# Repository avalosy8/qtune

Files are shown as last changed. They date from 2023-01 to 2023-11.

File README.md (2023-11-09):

# QTune: Automatic Guitar Tuner
This is a repository for an automatic guitar tuner project. 
This project utilizes the Adafruit Feather RP2040 with CircuitPython.

## Hardware Setup
1. Using the hooks and rubber bands, secure the device on the head of the guitar. Ensure that the tuning pegs are aligned within the tuning attachment that is connected to the servo motor.
2. Using the clip on attachment, clip the piezo sensor on the edge of the guitar's head.
3. Plug the USB to Type-C cable to the power bank and power it on to start the program.
4. Using the push buttons and LCD interface, follow the instructions displayed by the LCD.

## Software Installation
In order to start writing Python scripts for the RP2040, follow these steps:
1. Download the latest version of CircuitPython for the RP2040 here: https://circuitpython.org/board/adafruit_feather_rp2040/
2. Start the bootloader on the board by first plugging in the device, holding down the BOOTSEL button and then pressing the RESET button once. The board will now be mounted as an external filesystem with a name similar to RPI-RP2.
3. Copy the UF2 file onto the mounted board.
4. Connect to the REPL via USB serial port. This can be done using putty or nRF Terminal in VSCode for example.
5. Copy the repo and add the code.py file into the mounted board. The board should flash and run the code.
6. Connect to the USB serial port via the nRF terminal in VSCode or minicom if you're using a Mac.

## Usage
The board controls the servo motors and a LCD based on user input and the processed input frequency from the comparator circuit implementation. The comparator circuit is used to process the analog input from the vibration sensor and convert it to a digital output that can be interpreted in software.

The LCD is connected to two buttons, one button switches between the type of string to be tuned and the second button confirms the string selection. Information is displayed on the LCD as the program progresses.

All of the servo motors are screwed into a 3D printed case, which properly aligns the motors to each tuning peg of the guitar. This case also has two sets of hooks screwed in to allow rubber bands to securely wrap around the device and head of the guitar.

## Overall Procedure
1. Press one button to iterate through all the string options and press the other button to select the current string displayed on the LCD.
2. The selected string will then display on the LCD for a moment before the program initiates the frequency measurements and calculations.
3. As the program runs, it will first measure the frequency and compare it against the target frequency. When it's too low or too high, the LCD will notify the user and the motors will turn either left or right, moving the tuning peg. The user will also be prompted to strum the guitar string again.
4. While the program runs, the user also has the option to restart the program and select a different string to tune. The program restarts by pressing the rightmost button at any point after the program has initiated.
5. If the measured frequency is correct, then the tuning is completed and the program restarts. Otherwise, repeat step 3 until the desired frequency value is measured.

## Demo

Demo (https://www.youtube.com/watch?v=emY8-uXGGco)

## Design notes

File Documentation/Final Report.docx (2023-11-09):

Q-Tune: Final Report

Yenessa Avalos-Maldonado, Timothy Chiles, William Trigg, Giovanni Cornejo, and Dakota Cappel

Github Link: https://github.com/avalosy8/qtune

Abstract

The process of tuning a guitar can be a daunting task for guitarists, especially for beginner guitarists who have yet to develop the skill to tune a guitar by ear. Even experienced guitarists find it challenging to maintain their guitar in tune for extended periods. This project aims to tackle this problem by developing an automatic guitar tuner that can precisely and efficiently tune each string in a guitar. The tuner can analyze the frequency of the guitar string vibrations using a piezo sensor and provide instant adjustments using servo motors attached to each tuning peg of a guitar.

The tuner features a visual display using an LCD that helps guide the user throughout the tuning process by displaying the string selection, its targeted frequency, and overall tuning progress. Each tuning peg is attached to its own servo motor that twists the pegs. To maintain accuracy and reliability, the tuner utilizes a piezoelectric sensor to capture the vibration frequency from the string. Additionally, a rechargeable power bank is used to power the device via a USB type-C cable, which is connected to the Adafruit RP2040 microcontroller. In general, the tuner aims to develop a solution that can ease the process of tuning a guitar. The device is enclosed in a 3D-printed case that can clamp onto the head of the guitar. Ultimately, the project investigates how to enhance the overall guitar playing experience.

Introduction

The main goal of this project is to make the process of tuning a guitar easier, more accurate, and automated. Tuning an instrument is a universal struggle among musicians, and for guitarists this is no exception. Depending on how out of tune a guitar is, it can take as long as 15 to 20 minutes to get all strings back in tune. In addition, most guitarists must use a device that reads the note’s frequency and tells the guitarist whether it is still too high or low. While more experienced guitarists can memorize how each string sounds and tune it accurately, it still requires them to turn each peg an appropriate amount.

Our project intends to serve a need for all guitarists regardless of their skill level, which is to tune a guitar much faster by providing an easy-to-understand user interface. This user interface consists of a LCD screen and two buttons, and the latter allows the user to select which string they want to tune by cycling through the strings. Therefore, all the user must do is to attach the servos to the tuning pegs, select which string they want to tune, and strum the guitar until the LCD outputs a completion message. The screen can either tell the user to keep strumming, or that the tuning process is finished, while using a progression bar. The user can then move onto the next string, if needed. This overall improvement to the speed and reliability of the tuning process is something any guitarist will appreciate, and the stated elements above help achieve this improvement.

For this project, we largely focused on cultural, social and economic factors that could influence the development of our device. This includes the difficulty of upscaling production of our device because of its many separate parts, how the speed of setup would impact use among consumers, and the ability of novel guitarists to use the device to tune their guitar, to name a few. Considering our device involves moving servo parts, we would suggest that users refrain from putting their fingers near the tuning pegs as they turn. Otherwise, this project is largely disconnected from matters of public health, safety, or welfare.

Background

Analog guitar tuners were invented in 1936 and replaced with digital tuners in the 1980s. An issue that these original microphone-based guitar tuners exhibited was that they were much less effective in loud environments due to background noise. This issue was resolved in 1995 when the first clip-on guitar tuner was released that utilized a contact microphone that senses the physical vibrations of the guitar’s wood rather than the sound waves traveling through the air. Since this breakthrough, developments have been made towards automating the entirety of the tuning process. Automatic guitar tuners currently take two forms: the handheld motorized guitar tuners that the user must hold up to each string one by one (see Figure 1) and the built in guitar tuners that come installed in certain guitars (see Figure 2).

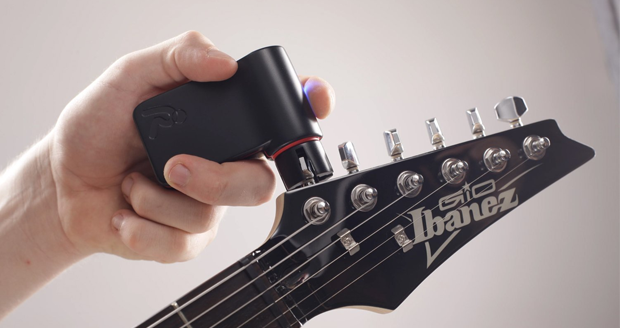
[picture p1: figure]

Figure 1: Handheld Automatic Guitar Tuner

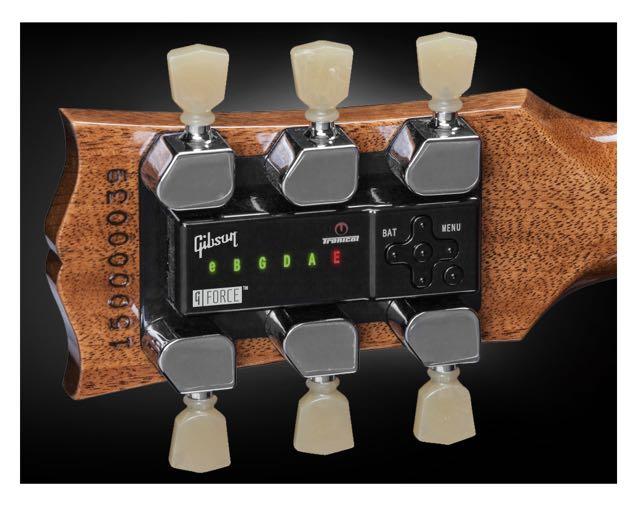
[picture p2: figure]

Figure 2: Built-in Automatic Guitar Tuner

Guitars produce sound via the oscillations of the strings when the strings are plucked. These oscillations get transferred to the body of the guitar via vibrations. The length, thickness, and tension of each guitar string determine the frequency with which the string will vibrate and, in turn, the note that the string will produce. Before playing, the frequency of each full-length string needs to be set to a reference note. Because the length and thickness of an open guitar string are constant, setting the reference note is achieved by adjusting the tension of the string with the tuning pegs at the head of the guitar. The standard reference notes and frequencies are, in order from top to bottom, E (82.41 Hz), A (110.00 Hz), D (146.83 Hz), G (196.00 Hz), B (246.94 Hz), and E (329.63 Hz). Guitar tuners convert the sound of each open string into an equivalent sinusoidal voltage, determine the sinusoid’s frequency, and compare it to these reference values to determine if the string is in tune.

While each guitar string vibrates primarily with its fundamental frequency, it technically oscillates at a superposition of its fundamental frequency and its harmonics, which are integer multiples of the fundamental frequency. To account for these other frequencies, different techniques could be utilized. One such approach would be to filter out the higher harmonic frequencies via analog or digital filtering techniques. While this approach could be used to filter out many of the harmonic frequencies producible by the guitar strings, it would not filter out the multiples of the lower frequency strings that are still smaller than the higher strings. Because the harmonics are integer multiples of the fundamental, a simple digital approach to account for harmonics would be to check for not only the fundamental frequency being present but to also check for twice the frequency, three times the frequency, and onwards.

As mentioned previously, contact microphones have widely been utilized in clip-on guitar tuners. Contact microphones are implemented using piezoelectric transducers. These sensors produce charge on their nodes that is proportional to the mechanical stress applied to their surfaces. These sensors are sensitive enough to pick up the small vibrations produced at the head of a guitar; however, the charge produced by such vibrations is very small. The signal produced by piezo sensors is often driven through an amplifier circuit to increase its amplitude to an appropriate level for subsequent circuitry.

Amplifiers with high input impedance are often used to match the high source impedance of piezo sensors. While voltage-mode amplifiers are often used, charge amplifiers are more recommended for piezo sensors. While the charge produced by the sensor produces a voltage across the piezo sensor’s two plates, this voltage is not necessarily proportional to the charge due to the ability of the capacitance to change between the two nodes. The capacitance can change because the two nodes are often connected to the circuitry via a cable. Changing this length of cable or even adjusting the cable could alter the capacitance of the cable and corrupt the signal from the piezo. Utilizing a charge amplifier nulls this effect as the charge is forced onto one of the plates of the feedback capacitor in the circuit whose value does not change. Additionally, a charge amplifier’s input resistance forms a high-pass filter with the piezo’s capacitance, and the feedback capacitor and resistor form a low-pass filter. The charge amplifier can thus be used to achieve a bandpass response which is useful in many applications.

When it comes to motors, there are many types of motors that could be used to tune a guitar. Servo motors can offer a large amount of torque while limiting the size and the power needed. Using three wires, ground, power, and data, the servo motors can be controlled through pulses from a microcontroller pin. The data channel for the servo motor is constantly receiving pulses from the controller. When wanting to move the motor with a certain power, the width of this pulse changes to a certain value, indicating the motor to move. This type of communication is called Pulse-width modulation. Servos can come in limited rotation or full 360 degree rotation. Both operate in the same manner, however, the limited rotation only offers about 180 degrees of rotation. This can be useful in some cases, but for a guitar tuner, a full 360 rotation is required to ensure that the tuner can always turn each way no matter where it starts.

Timeline

We began the project with some research on how we might develop an automatic guitar tuner. This research led us towards a plan to use a piezoelectric transducer to sense the vibrations of the guitar strings in conjunction with servo motors to turn the motors based on a frequency calculation. To bootstrap the project for the pre-alpha build, we utilized parts we had on hand and began experimenting with calculating frequencies and turning servo motors. We decided that the simplest method would be to convert the sinusoids from a guitar into a square wave and calculate the frequency by timing the period between rising edges. To convert the sinusoids into square waves, we constructed a simple op-amp comparator circuit. Because we had not acquired a piezoelectric sensor yet, we fed sinusoids into the comparator using a waveform generator. We utilized an oscilloscope to verify that the comparator successfully converted the inputted sinusoid into a square wave with the same frequency. During this process, we utilized CircuitPython on our Adafruit RP2040 microcontroller to quickly get a simple micro servo motor to turn clockwise and counterclockwise. Because we planned to use interrupts to time the periods of the square waves from the comparator, we were led to utilize asyncio in CircuitPython to get interrupt-like functionality that could successfully calculate the frequency of our square waves.

When progressing towards our prototype build, we realized that the servo we were using could only turn 90 degrees in both directions which would not suit our needs if our guitar was more than a quarter-turn out of tune. We ordered continuous servo motors that could continuously turn clockwise or counterclockwise and rewrote our code to accommodate these new motors. In addition, we wrote functions that could rotate the servo motors in increments in either direction based on the frequency that another section of our code calculated. We introduced the UI during the prototype phase but did not connect them to the remainder of the tuner. We acquired a piezo sensor during this period and began testing our comparator circuit/firmware with it. We initially played pure tones on our laptop speakers and attempted to pick up the vibrations with our sensor. Testing the piezo with speakers and then a guitar introduced a lot of randomness and inconsistency with our analog signal and thus our frequency we calculated in our firmware. One of the causes of the inconsistency we discovered was that there was an input DC offset that our comparator would introduce to our piezo’s AC signal that would change over time and affect our outputted square waves. We implemented safety guards in code to ignore frequencies that were too far from the frequency of the current string being tuned to account for the noise. In addition, inaccuracies in our calculated frequencies would arise in the code due to how we were directly timing the periods of the square waves.

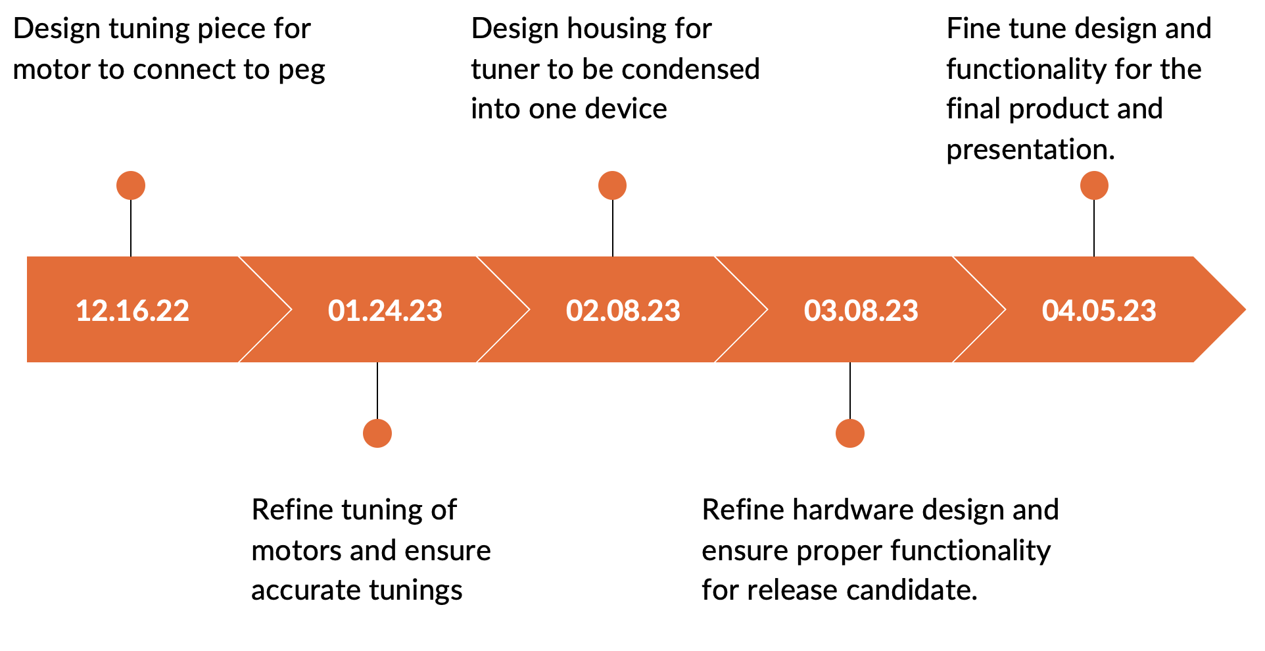
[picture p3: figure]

Figure 4: Prototype Project Timeline

For our alpha build, we primarily upgraded our motor turning and UI systems to better test our ability to tune a guitar. We upgraded our micro servos to much larger servos that could actually turn the tuning pegs of a guitar. In addition, we designed and 3D printed attachments that could attach the motors to the tuning pegs to allow them to turn the pegs. We integrated the UI with the rest of the design and began testing the whole tuning process. We altered sections of the code to get the frequency calculations to be more accurate despite the added complexity of the motors; however, we still had the same inconsistency problems as during the prototype phase.

We addressed the inconsistencies in the frequency calculations during the beta build phase of the project. After much research and experimentation, we designed a charge amplifier circuit to amplify our piezo signal. We discovered that very high frequencies were appearing at the output of our charge amplifier and designed a bandpass filter to filter these frequencies and undesired low frequencies out. To get rid of the changing DC offset that we were experiencing, we added an AC coupling capacitor to block an DC component from entering the comparator. After many bandpass filtering attempts, we realized that the large frequencies we were noticing were the 2nd harmonics of the strings we were strumming. To account for these 2nd harmonics, we added checks in code to check for double the desired frequencies. During this phase, we expanded to 6 motors with tuning attachments.

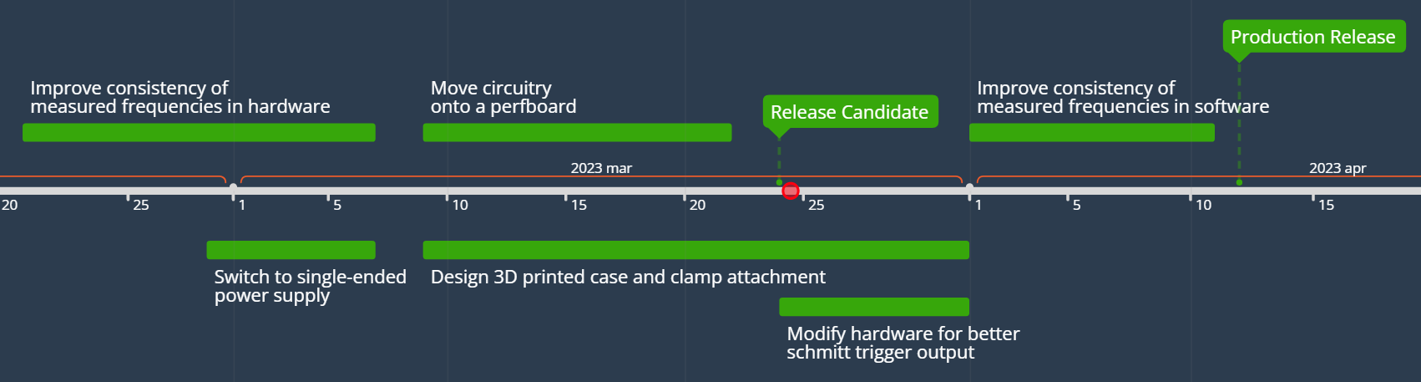
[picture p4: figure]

Figure 5: Project Timeline (Beta Build - Production Release)

Because most of the high frequencies were just 2nd harmonics, we removed the discrete bandpass filter for the release candidate. We also moved all of our circuitry to a single 3.3V supply during this phase. Despite all of the improvements to the signal conditioning circuitry, we still had a lot of inconsistency and inaccuracy in calculating frequencies. We shifted our circuitry to a perfboard and used a higher quality piezo cable to remove some randomness from the circuitry. We also shifted to an actual comparator based square wave generator rather than an op-amp based one. We added hysteresis to the comparator to prevent faulty triggering due to noisy signals. Due to the problems we were having discretely timing square wave periods while turning motors in the background, we shifted away from asyncio and found a synchronous way to calculate frequencies/turn the motors. We utilized the pulsein function, averaging, and other statistics to get a very accurate frequency that we tested against other commercial guitar tuners. We designed a case that could house the motors and all circuitry to mount to the headstock of a guitar and line up the motors, the piezo sensor. This case would attach to the guitar via clamps.

For the production release, we removed the clamps and utilized rubber bands to strap the tuner case to the guitar. We made aesthetic changes to our tuner case as well as some LCD messaging changes to enhance the user experience such as adding a tuning progress notification. We did further testing to enhance the performance of the tuner.

Design

The QTune automatic guitar tuner comprises three peripheral systems: the frequency measurement system, the tuning peg turning system, and the user interface system. The functionality of and communication between these peripheral systems is handled by an Adafruit RP2040 microcontroller whose firmware is written with CircuitPython. All these components physically interface with the guitar via a custom 3D printed case and are powered by a USB power bank.

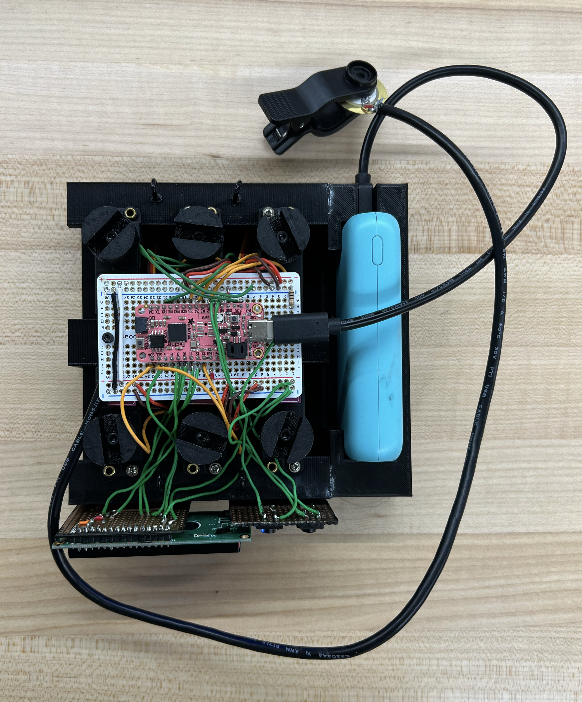
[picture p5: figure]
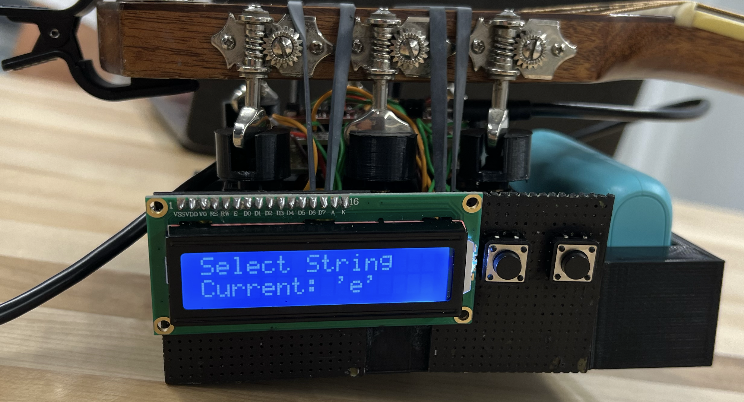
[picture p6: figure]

Figure 3: Top down view of the completed Release Candidate (left). Side view of the device clamped onto the guitar, with the motor tuning attachment properly fitting onto the guitar’s tuning pegs (right).

The frequency measurement system assesses the state of each guitar string as it is tuned by determining the frequency with which the string is vibrating after it is plucked by the user. The tuning peg turning system either turns the string in question clockwise, counterclockwise, or not at all depending on the state of the string reported by the frequency measurement system. The user interface allows users to choose the string that they wish to tune, informs them of when they need to pluck the string, and reports on the progress of the string being tuned with information from the frequency measurement system.

To determine the frequency of the guitar strings, our tuner utilizes a piezoelectric transducer sensor mounted to the headstock of the guitar. The piezoelectric sensor’s positive and negative nodes are wired through a shielded cable into a charge amplifier circuit that amplifies the sensor’s sinusoidal output. The sensor type, input resistor, feedback resistor, and feedback capacitor values were selected to create a passband of around 60 Hz - 360 Hz to filter out frequencies that the guitar could not produce. The sinusoidal output of the charge amplifier is then fed through a schmitt trigger circuit that converts the signal into a clean 0V - 3.3V square wave to be processed by the microcontroller.

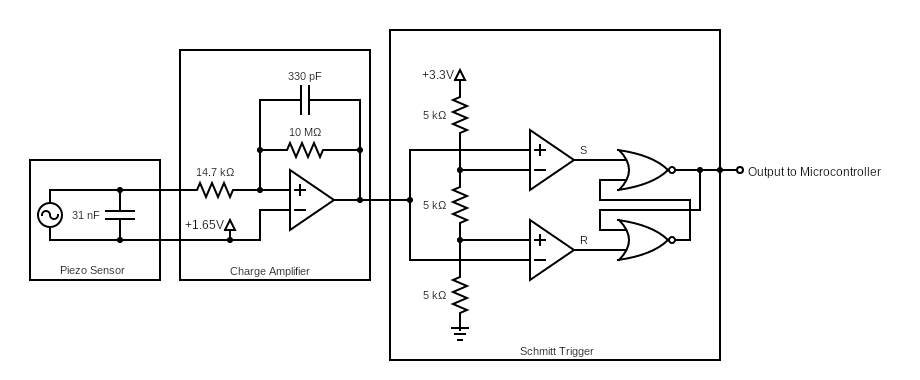
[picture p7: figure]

Figure 6: Piezoelectric Signal Conditioning Circuitry

The frequency is calculated based on the amount of time required for one rising edge and one falling edge - or one period - to be completed, and then taking the reciprocal. This is done via the pulseio module of CircuitPython, which measures a series of active and idle pulses that are read from the rx pin of the microcontroller and stores the times in an array. Accuracy is assured by using the average period time of the array before calculating the frequency. The length of each sample is determined by which note is being played, as higher frequencies require a larger series to maintain accuracy. Precision is assured by repeating this process and storing each measured frequency in another array until ten samples are reached. Only values around the interquartile range are used to remove outliers and then are averaged again to get the final frequency.

The previously calculated frequency will then be compared against the target frequency. The servo attached to the corresponding tuning peg will move either clockwise or counterclockwise depending on if it is higher or lower than the target frequency. If it is within ± 0.5 Hz of the actual value, then it is considered to be in tune and the tuning process is finished.

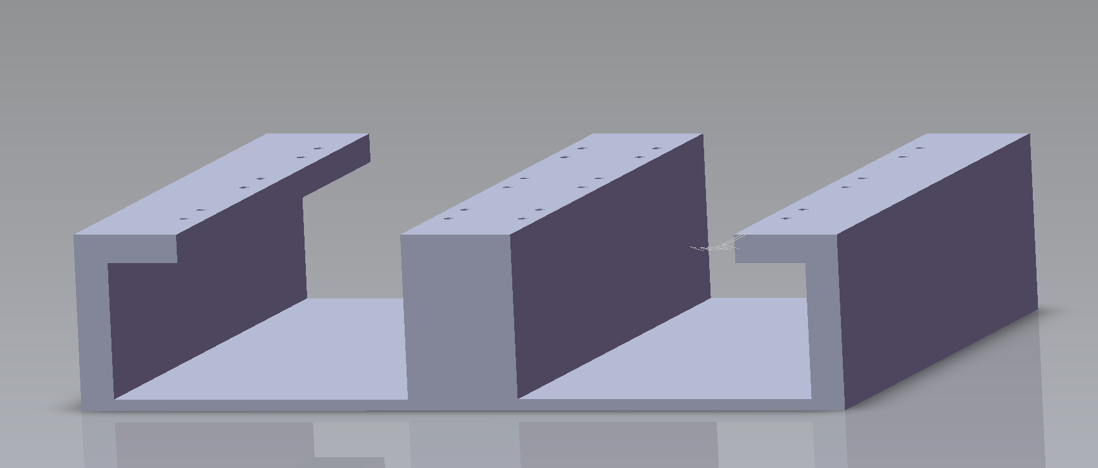
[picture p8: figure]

Figure 7: Finalized case for containing the servo motors, designed in Solidworks. The indicated holes align the motors to the correct tuning pegs.

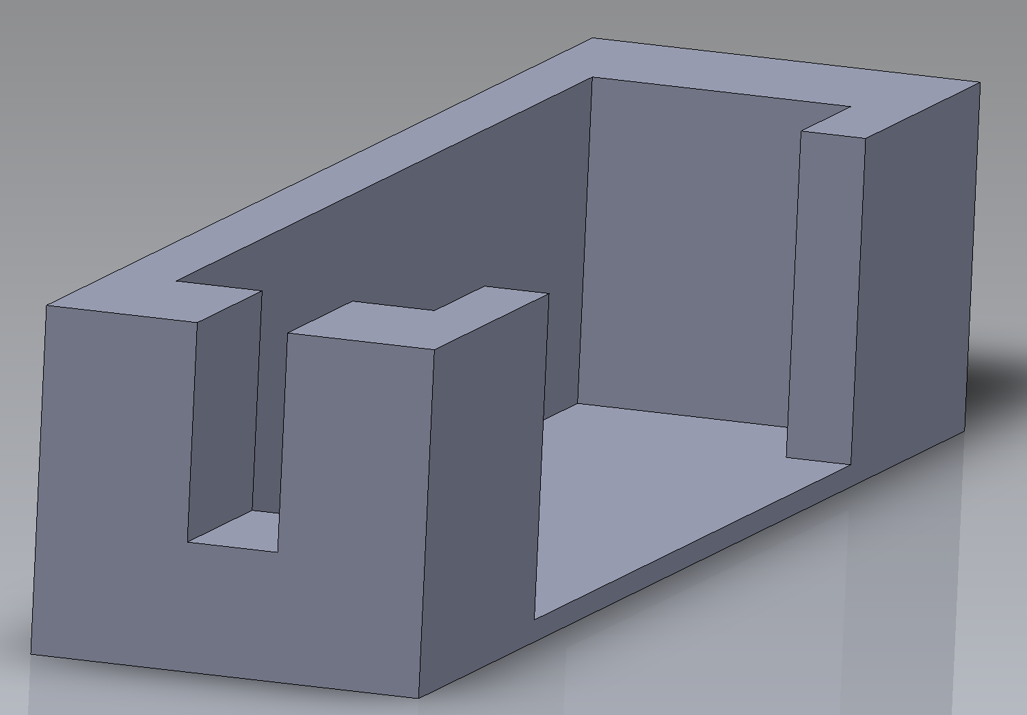
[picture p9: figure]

Figure 8: Finalized case for the power bank, designed in Solidworks.

Impact

To focus on the impact of this project, it’s important to focus on its positive impacts first, starting with its cultural and social impacts. Because this project intends to make the tuning process easier, it allows newer guitarists to continue developing their skills without having to worry about their guitar falling out of tune. This project also removes a learning barrier with people that struggle to get into playing guitar, so more people can actually become musicians. In general, this process should allow more people to become interested in making music, and since music is so intertwined with cultural developments, this project can help develop cultural trends if optimized to its fullest. The device’s compactness, speed of setup, and cost can be further improved with more development time and a generally better piezoelectric sensor. We believe that the device could get this introduction into the industry through smaller record companies or bands, as they could better compete with larger firms and their more advanced technology by speeding up the tuning process. The faster this goes, the easier for them to produce music, and change music and cultural trends sooner.

Considering its cultural and social impacts, one must also recognize its global impact. If this device proves to be a quick and effective tool for tuning guitars, then the technology should be able to spread globally for anyone to use. While English isn’t universally spoken, most countries around the world should be able to understand the technology due to its simplicity and the widespread use of English too. Because our coding is open for anyone to edit, anyone can edit the intended frequencies of each guitar string to tune the guitar to a different key, mode, etc.

In contrast, it’s important to highlight a drawback of the device- its environmental impact. This project requires an external battery source and multiple integrated circuits, and the byproducts of these electronics are often released in wastewater from PCB production facilities. These include chemical agents used to treat the perfboards, heavy metals such as copper and iron, and organic contaminants from the etching process. According to the study done by Geric, et. al, the results demonstrated that the concentration of contaminants of the wastewater was both cytotoxic (decreased viability) and genotoxic (can damage DNA) to human white blood cells. This leaves people more prone to getting sick, among other things. While treating the wastewater is highly effective at controlling this runoff, a lack of regulation can easily lead to contamination of surrounding environments.

Lastly, consider the economic impact of this project. Below is a running total of all the items used for creating the project and their associated costs. The 3D printed casing was done by the Marston Science Library printing lab. Do note that these costs could improve given ownership of a 3D printer and control of production of the servo motors.

Cost Breakdown:

Adafruit IC- $12

3D Printed Main-Body Casing - $15

3D-Printed Battery Case - $7

Piezoelectric Sensors (15 count) - $8

Servo Motors (2 for $16) - $48

Battery Pack- $10

Perfboards ($4.50 each) - $9

The whole cost of the device is approximately $110 dollars, and from a consumer aspect the economic impact becomes clear. Each device produced would cost at least that amount in order to break even, and even more to make a profit. Considering this and other options that consumers have at their disposal for tuning their guitars, they might forgo the automatic aspect of the project and opt for manual tuning with a listening device. Therefore, the economic impact of this project, if realistically marketed and sold in stores, would be limited. The focus would be on the automatic aspect of this device, and its ease of use would see a more niche group of consumers that would want to purchase it, such as beginning musicians.

Finally, in its current state, the device’s main limitation is the sensitivity of the piezo sensor. The comparator circuit and software can read and process all signals correctly, but at certain times, a few strings will have a very short time period where an accurate frequency can be read and processed. This is remedied through multiple strums, but the intended response is to have as few strums as possible. We have attempted to remedy this by shortening the pauses between data collection, with some success.

Results

Alpha Tests

a. Powering/Turning servos
  i. After determining that we had enough available pins on the Adafruit board, we connected all six servo motors and tested different voltages to find the proper voltage level needed to power the motors. After testing, we concluded that 5V was enough to power the motors. We no longer use the default 3.3V on the Adafruit board and instead use the USB pin to obtain 5V.
b. Determining total power required
  i. After testing, we concluded that all components of our guitar tuner could be powered simultaneously via the 5V and 3.3V pins on the Adafruit board. The Adafruit board could successfully power its internal components, the LCD display, the piezo sensor’s circuitry, and at least 1 servo motor at a time via a USB power bank plugged into its USB-C port. We determined that a USB power bank is a suitable power source for our final tuner design as it can make the whole tuner rechargeable and easily able to be turned on and off.
c. Testing 3D printed tuning attachment
  i. Once the tuning attachment design was finalized and printed, we screwed the attachments onto each servo motor and tested them against each tuning peg. We turned the motor in small increments and tested how much strength was needed to turn the tuning peg. After testing, we’ve concluded that the tuning attachment design was a suitable shape for turning the tuning pegs.
d. Testing tuner for each string
  i. As we began testing the accuracy of our tuner, we determined that more circuitry was required to condition the signal from our piezo sensor (amplification, filtering, noise reduction, removal of DC offset). After implementing this new functionality, we encountered an issue where the second harmonic of each string was appearing more so than the fundamental frequency we were looking for. We added to our code to account for this issue. When testing our tuner after these progressions, we achieved our first successful tuning of the low E string.

Beta Tests

a. Guitar string accuracy
  i. In order to ensure that the software was reading the frequencies correctly for each string, we performed a variety of tests for each string. First, we used the DAD and fed in the comparator output to the oscilloscope and had WaveForms calculate the frequency to make sure the comparator was accurate. We compared these results to a clip-on tuner. We then ran the program on the adafruit and had it calculate the frequency and compared it to both the DAD and the clip-on tuner to ensure accuracy. We then put each string out of tune and made sure that software continued to record accurate frequencies. All of these tests were successful, with the software recording nearly perfect readings each time.
b. Motor Tests
  i. We then used the frequency data to feed into the motors to turn the proper direction. We went through each string and put them out of tune and ran through each string and ensured that the motors could properly tune the string within a certain threshold. We first started with a large frequency threshold and slowly made the threshold smaller to make sure the motors could tune very accurately. These tests were very successful with the tuner being able to tune within +/-0.5 Hz.
c. Environmental Tests
  i. We then tested the guitar in different positions to make sure that this did not have an effect on the readings of the guitar and motors tuning. Upon moving the guitar to different positions, such as being held normally instead of flat on the table, the tuner continued to work as expected.
d. Durability Tests
  i. To test durability, we attached the tuner to the end of the guitar and moved it as a normal guitarist might and made sure the tuner did not move much. The tuner would stay on with our current clamp design, however with too much movement, the tuner may fall off. This is expected though, as the design is supposed to be removable and therefore too much movement could potentially make it fall off. With normal, non rigorous movements, the tuner is very stable.

The completed hardware elements of the project include a 3D printed case enclosing all components. Measurements for component lengths and the guitar were taken using a caliper for construction of the case in SolidWorks. This contains the six motors that are each attached to a tuning peg and a small hub that holds a rechargeable power bank to power the device and the LCD and push button user interface. The interface is attached to the outside of the case and painted to match. The circuitry itself has been condensed onto a perfboard to fit neatly between the motors. Consisting of the charge amplifier and schmitt trigger circuits, the output is sent to a secondary perfboard that holds the Adafruit RP2040 microcontroller. All wired connections are also hidden within the case. The enclosure is attached to the guitar with elastic bands that attach to hooks on opposite sides of the device. The tuning pegs of the guitar then fit precisely into the motors of the device allowing the motors to efficiently and accurately tune the guitar.

As for software, the frequency measurements have been cleaned up to produce very accurate results, with frequency readings being almost perfect (within +/- 0.1Hz) in the best case. This allows the device to tune the guitar to within +/- 0.5Hz of the desired frequency. The LCD display continuously shows the current progress of the tuning, notifying users when the tuning is done. The software has also been modified to turn the motors for longer the more out of tune the string is, and shorter the closer it gets, producing much quicker and more accurate results. The users are now also able to exit a tuning and return to the initialization screen if they select the wrong string.

Conclusion

In conclusion, the automatic guitar tuner project aims to develop an innovative solution that can reliably automate the process of tuning a guitar. With features such as an LCD interface with buttons and accurate frequency measurements, the tuner will provide reliable and consistent tuning for both beginners and experienced guitarists. To ensure the device tunes as precisely and accurately as possible, multiple tests and adjustments were made to the design of the tuner throughout the whole process while following proper engineering practices.

Ultimately, the project seeks to enhance the quality and enjoyment of the guitar playing experience, which is done using the device’s intuitive and responsive interface. This device will enhance the guitar playing experience by minimizing the frustrations and time it takes to tune a guitar. Especially for beginner guitarists who have yet developed good intonation, this device will help aspiring guitarists jumpstart their musical journey without having to worry about knowing how to tune.

References

1. Colin, “Guitar tuners 101: The Ultimate Buyer's Guide,” E-Home Recording Studio, 02-Mar-2023. [Online]. Available: https://ehomerecordingstudio.com/best-guitar-tuners/. [Accessed: 24-Mar-2023].
2. E. Moffatt, “Nashville-based Gibson says self-tuning guitars are here to stay,” 90.3 WPLN News, 29-Jun-2015. [Online]. Available: https://wpln.org/post/nashville-based-gibson-says-self-tuning-guitars-are-here-to-stay/. [Accessed: 24-Mar-2023].
3. Evstark and Evstark, “Modeling and experimental tools with prof. magnes,” Modeling and Experimental Tools with Prof Magnes, 12-May-2019. [Online]. Available: https://pages.vassar.edu/magnes/2019/05/12/studying-and-modeling-guitar-harmonics-using-fourier-analysis/. [Accessed: 24-Mar-2023].
4. J. Karki, “Signal conditioning piezoelectric sensors - Texas Instruments,” TI, Sep-2000. [Online]. Available: https://www.ti.com/lit/an/sloa033a/sloa033a.pdf. [Accessed: 25-Mar-2023].
5. M. Gerić, G. Gajski, V. Oreščanin, A.-M. Domijan, R. Kollar, and V. Garaj-Vrhovac, “Environmental risk assessment of wastewaters from printed circuit board production: A multibiomarker approach using human cells Author links open overlay panel,” ScienceDirect, Feb-2017. [Online]. Available: https://doi.org/10.1016/j.chemosphere.2016.10.101. [Accessed: 24-Mar-2023].
6. “Roadie Tuner Automatic guitar tuner,” Agazoo, 10-Jun-2015. [Online]. Available: https://agazoo.com/offers/unique-gadgets/roadie-tuner-automatic-guitar-tuner/. [Accessed: 24-Mar-2023].
7. “Piezo tuners - the clip on Tuner,” SWAMP Industries, 26-Oct-2022. [Online]. Available: https://www.swamp.net.au/articles/piezo-tuners.html. [Accessed: 24-Mar-2023].

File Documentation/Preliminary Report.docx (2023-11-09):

Q-Tune: Preliminary Report

Yenessa Avalos-Maldonado, Timothy Chiles, William Trigg, Giovanni Cornejo, and Dakota Cappel

Github Link: https://github.com/avalosy8/qtune

Abstract

The process of tuning a guitar can be a daunting task for guitarists, especially for beginner guitarists who have yet to develop the skill to tune a guitar by ear. Even experienced guitarists find it challenging to maintain their guitar in tune for extended periods. This project aims to tackle this problem by developing an automatic guitar tuner that can precisely and efficiently tune each string in a guitar. The tuner can analyze the frequency of the guitar string strums using a piezo sensor and provide instant adjustments using servo motors.

The tuner features a visual display using an LCD that helps guide the user throughout the tuning process by displaying the string selection, its targeted frequency, and overall tuning progress. Each tuning peg is attached to its own servo motor that twists the pegs. To maintain accuracy and reliability, the tuner utilizes a piezoelectric sensor to capture the vibration frequency from the string. Additionally, a rechargeable power bank is used to power the device via a USB type-C cable, which is connected to the Adafruit RP2040 microcontroller. In general, the tuner aims to develop a solution that can ease the process of tuning a guitar. The overall device is enclosed in a 3D-printed case that can clamp onto the head of the guitar. Ultimately, the project investigates enhancing the overall guitar playing experience.

Introduction

The main goal of this project is to make the process of tuning a guitar easier, more accurate, and automated. Tuning an instrument is a universal struggle among musicians, and for guitars this is no exception. Depending on how out of tune a guitar is, it can take as long as 15 to 20 minutes to get all strings back in tune. In addition, most guitarists must use a device that reads the note’s frequency and tells the guitarist whether it is still too high or low. While more experienced guitarists can memorize how each string sounds and tune it accurately, it still requires them turning each peg an appropriate amount.

Our project intends to serve a need for all guitarists regardless of their skill level, which is to tune a guitar much faster by providing an easy-to-understand user interface. This user interface consists of a LCD screen and two buttons, and the latter allows the user to select which string they want to tune by cycling through the strings. Therefore, all the user must do is to attach the servos to the tuning pegs by turning them, select which string they want to tune, and strum the guitar until the LCD outputs a completion message. The screen can either tell the user to keep strumming, or that the tuning process is finished. The user can then move onto the next string, or they are done tuning. This overall improvement to the speed and reliability of the tuning process is something any guitarist will appreciate, and the stated elements above help achieve this improvement.

Background

Analog guitar tuners were invented in 1936 and replaced with digital tuners in the 1980s. An issue that these original microphone-based guitar tuners exhibited was that they were much less effective in loud environments due to background noise. This issue was resolved in 1995 when the first clip-on guitar tuner was released that utilized a contact microphone that senses the physical vibrations of the guitar’s wood rather than the sound waves traveling through the air. Since this breakthrough, developments have been made towards automating the entirety of the tuning process. Automatic guitar tuners currently take two forms: the handheld motorized guitar tuners that the user must hold up to each string one by one (see Figure 1) and the built in guitar tuners that come installed in certain guitars (see Figure 2).


Figure 1: Handheld Automatic Guitar Tuner


Figure 2: Built-in Automatic Guitar Tuner

Guitars produce sound via the oscillations of the strings when the strings are plucked. These oscillations get transferred to the body of the guitar via vibrations. The length, thickness, and tension of each guitar string determine the frequency with which the string will vibrate and, in turn, the note that the string will produce. Before playing, the frequency of each full-length string needs to be set to a reference note. Because the length and thickness of an open guitar string are constant, setting the reference note is achieved by adjusting the tension of the string with the tuning pegs at the head of the guitar. The standard reference notes and frequencies are, in order from top to bottom, E (82.41 Hz), A (110.00 Hz), D (146.83 Hz), G (196.00 Hz), B (246.94 Hz), and E (329.63 Hz). Guitar tuners convert the sound of each open string into an equivalent sinusoidal voltage, determine the sinusoid’s frequency, and compare it to these reference values to determine if the string is in tune.

While each guitar string vibrates primarily with its fundamental frequency, it technically oscillates at a superposition of its fundamental frequency and its harmonics, which are integer multiples of the fundamental frequency. To account for these other frequencies, different techniques could be utilized. One such approach would be to filter out the higher harmonic frequencies via analog or digital filtering techniques. While this approach could be used to filter out many of the harmonic frequencies producible by the guitar strings, it would not filter out the multiples of the lower frequency strings that are still smaller than the higher strings. Because the harmonics are integer multiples of the fundamental, a simple digital approach to account for harmonics would be to check for not only the fundamental frequency being present but to also check for twice the frequency, three times the frequency, and onwards.

As mentioned previously, contact microphones have widely been utilized in clip-on guitar tuners. Contact microphones are implemented using piezoelectric transducers. These sensors produce charge on their nodes that is proportional to the mechanical stress applied to their surfaces. These sensors are sensitive enough to pick up the small vibrations produced at the headstock of a guitar; however, the charge produced by such vibrations is very small. The signal produced by piezo sensors is often driven through an amplifier circuit to increase its amplitude to an appropriate level for subsequent circuitry.

Amplifiers with high input impedance are often used to match the high source impedance of piezo sensors. While voltage-mode amplifiers are often used, charge amplifiers are more recommended for piezo sensors. While the charge produced by the sensor produces a voltage across the piezo sensor’s two plates, this voltage is not necessarily proportional to the charge due to the ability of the capacitance to change between the two nodes. The capacitance can change because the two nodes are often connected to the circuitry via a cable. Changing this length of cable or even adjusting the cable could alter the capacitance of the cable and corrupt the signal from the piezo. Utilizing a charge amplifier nulls this effect as the charge is forced onto one of the plates of the feedback capacitor in the circuit whose value does not change. Additionally, a charge amplifier’s input resistance forms a high-pass filter with the piezo’s capacitance, and the feedback capacitor and resistor form a low-pass filter. The charge amplifier can thus be used to achieve a bandpass response which is useful in many applications.

When it comes to motors, there are many types of motors that could be used to tune a guitar. Servo motors can offer a large amount of torque while limiting the size and the power needed. Using three wires, ground, power, and data, the servo motors can be controlled through pulses from a microcontroller pin. The data channel for the servo motor is constantly receiving pulses from the controller. When wanting to move the motor with a certain power, the width of this pulse changes to a certain value, indicating the motor to move. This type of communication is called Pulse-width modulation. Servos can come in limited rotation or full 360 degree rotation. Both operate in the same manner, however, the limited rotation only offers about 180 degrees of rotation. This can be useful in some cases, but for a guitar tuner, a full 360 rotation is required to ensure that the tuner can always turn each way no matter where it starts.

Design

The QTune automatic guitar tuner comprises three peripheral systems: the frequency measurement system, the tuning peg turning system, and the user interface system. The functionality of and communication between these peripheral systems is handled by an Adafruit RP2040 microcontroller whose firmware is written with CircuitPython. All these components physically interface with the guitar via a custom 3D printed case and are powered by a USB power bank.

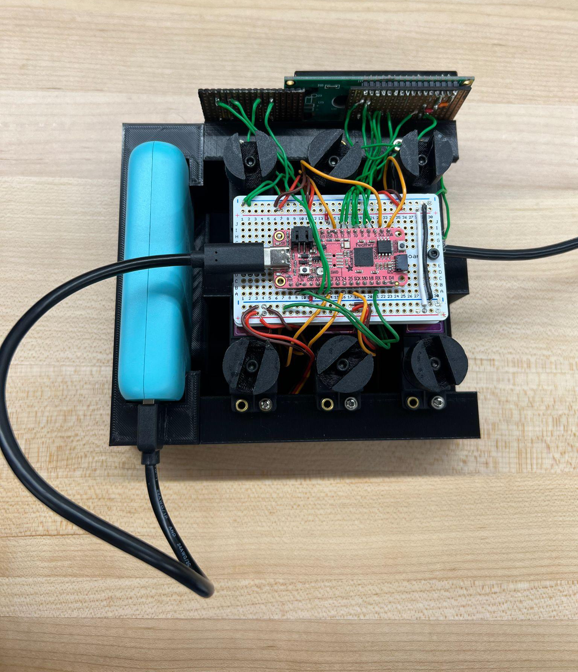
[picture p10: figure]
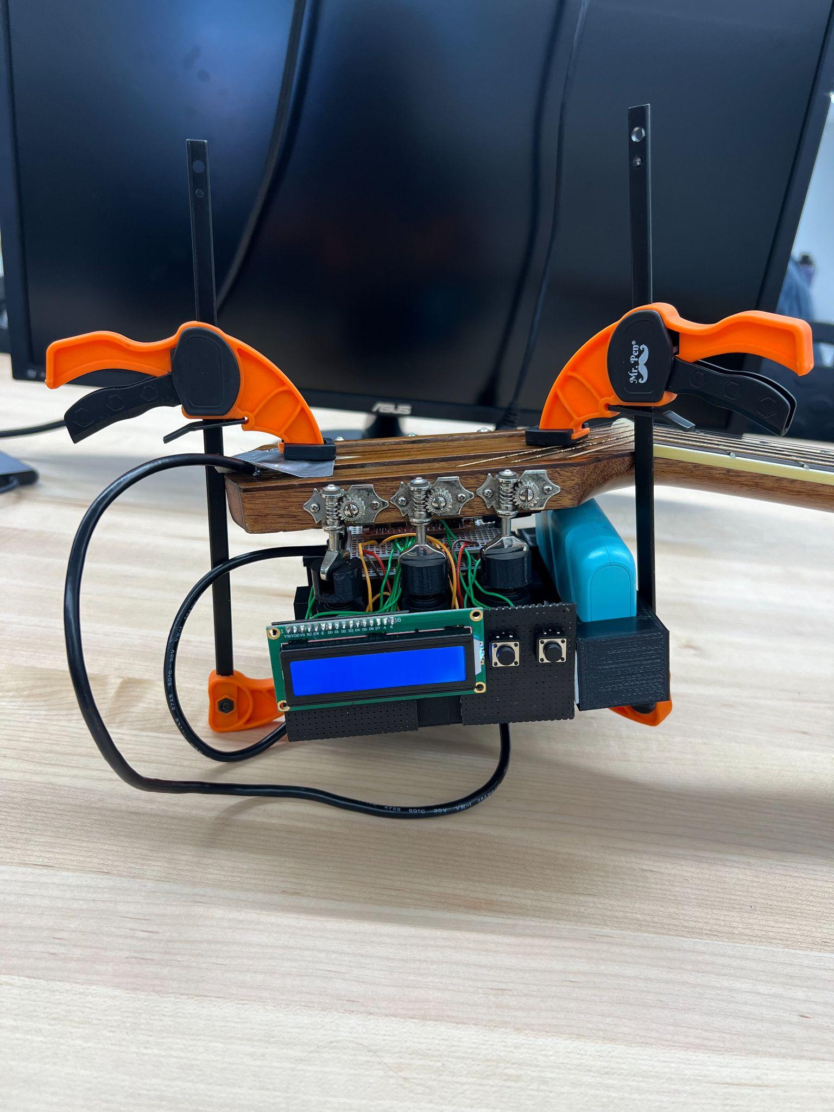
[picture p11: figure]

Figure 3: Top down view of the completed Release Candidate (left). Side view of the device clamped onto the guitar, with the motor tuning attachment properly fitting onto the guitar’s tuning pegs (right).

The frequency measurement system assesses the state of each guitar string as it is tuned by determining the frequency with which the string is vibrating after it is plucked by the user. The tuning peg turning system either turns the string in question clockwise, counterclockwise, or not at all depending on the state of the string reported by the frequency measurement system. The user interface allows users to choose the string that they wish to tune, informs them of when they need to pluck the string, and reports on the progress of the string being tuned with information from the frequency measurement system.

To determine the frequency of the guitar strings, our tuner utilizes a piezoelectric transducer sensor mounted to the headstock of the guitar. The piezoelectric sensor’s positive and negative nodes are wired through a shielded cable into a charge amplifier circuit that amplifies the sensor’s sinusoidal output. The sensor type, input resistor, feedback resistor, and feedback capacitor values were selected to create a passband of around 60 Hz - 360 Hz to filter out frequencies that the guitar could not produce. The sinusoidal output of the charge amplifier is then fed through a schmitt trigger circuit that converts the signal into a clean 0V - 3.3V square wave to be processed by the microcontroller.


Figure 4: Piezoelectric Signal Conditioning Circuitry

The frequency is calculated based on the amount of time required for one rising edge and one falling edge - or one period - to be completed, and then taking the reciprocal. This is done via the pulseio module of CircuitPython, which measures a series of active and idle pulses that are read from the rx pin of the microcontroller and stores the times in an array. Accuracy is assured by using the average period time of the array before calculating the frequency. The length of each sample is determined by which note is being played, as higher frequencies require a larger series to maintain accuracy. Precision is assured by repeating this process and storing each measured frequency in another array until ten samples are reached. Only values around the interquartile range are used to remove outliers and then are averaged again to get the final frequency.

The previously calculated frequency will then be compared against the target frequency (the note being tuned). The servo attached to the corresponding tuning peg will move clockwise or counterclockwise depending on if it is higher or lower than the target frequency. If it is within ± 1 Hz of the actual value, then it is considered to be in tune and the tuning process is finished.


Figure 5: Case for containing the servo motors, designed in Solidworks. The indicated holes align the motors to the correct tuning pegs.

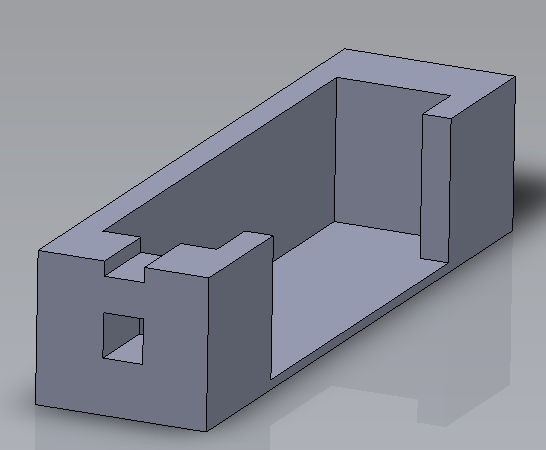
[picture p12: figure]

Figure 6: Case for the power bank, designed in Solidworks.

Impact

This project’s impact will be mostly cultural. Because this project intends to make the tuning process easier, it allows newer guitarists to continue developing their skills without having to worry about their guitar falling out of tune. This should allow more people to become interested in making music, and since music is so intertwined with cultural developments, this project can help develop cultural trends if optimized to its fullest.

In contrast, it’s important to highlight a drawback of the device- its environmental impact. This project requires an external battery source and multiple integrated circuits, and the byproducts of these electronics are often released in wastewater from PCB production facilities. These include chemical agents used to treat the perfboards, heavy metals such as copper and iron, and organic contaminants from the etching process. According to the study done by Geric, et. al, the results demonstrated that the concentration of contaminants of the wastewater was both cytotoxic (decreased viability) and genotoxic (can damage DNA) to human white blood cells. While treating the wastewater is highly effective at controlling this runoff, a lack of regulation can easily lead to contamination of surrounding environments.

Lastly, in its current state, the device’s main limitation is the sensitivity of the piezo sensor. The comparator circuit and software can read and process all signals correctly, but at certain times, a few strings will have a very short time period where an accurate frequency can be read and processed. This is remedied through multiple strums, but the intended response is to have as few strums as possible.

Results

Alpha Tests

a. Powering/Turning servos
  i. After determining that we had enough available pins on the Adafruit board, we connected all six servo motors and tested different voltages to find the proper voltage level needed to power the motors. After testing, we concluded that 5V was enough to power the motors. We no longer use the default 3.3V on the Adafruit board and instead use the USB pin to obtain 5V.
b. Determining total power required
  i. After testing, we concluded that all components of our guitar tuner could be powered simultaneously via the 5V and 3.3V pins on the Adafruit board. The Adafruit board could successfully power its internal components, the LCD display, the piezo sensor’s circuitry, and at least 1 servo motor at a time via a USB power bank plugged into its USB-C port. We determined that a USB power bank is a suitable power source for our final tuner design as it can make the whole tuner rechargeable and easily able to be turned on and off.
c. Testing 3D printed tuning attachment
  i. Once the tuning attachment design was finalized and printed, we screwed the attachments onto each servo motor and tested them against each tuning peg. We turned the motor in small increments and tested how much strength was needed to turn the tuning peg. After testing, we’ve concluded that the tuning attachment design was a suitable shape for turning the tuning pegs.
d. Testing tuner for each string
  i. As we began testing the accuracy of our tuner, we determined that more circuitry was required to condition the signal from our piezo sensor (amplification, filtering, noise reduction, removal of DC offset). After implementing this new functionality, we encountered an issue where the second harmonic of each string was appearing more so than the fundamental frequency we were looking for. We added to our code to account for this issue. When testing our tuner after these progressions, we achieved our first successful tuning of the low E string.

Beta Tests

a. Guitar string accuracy
  i. In order to ensure that the software was reading the frequencies correctly for each string, we performed a variety of tests for each string. First, we used the DAD and fed in the comparator output to the oscilloscope and had WaveForms calculate the frequency to make sure the comparator was accurate. We compared these results to a clip-on tuner. We then ran the program on the adafruit and had it calculate the frequency and compared it to both the DAD and the clip-on tuner to ensure accuracy. We then put each string out of tune and made sure that software continued to record accurate frequencies. All of these tests were successful, with the software recording nearly perfect readings each time.
b. Motor Tests
  i. We then used the frequency data to feed into the motors to turn the proper direction. We went through each string and put them out of tune and ran through each string and ensured that the motors could properly tune the string within a certain threshold. We first started with a large frequency threshold and slowly made the threshold smaller to make sure the motors could tune very accurately. These tests were very successful with the tuner being able to tune within +/-1Hz.
c. Environmental Tests
  i. We then tested the guitar in different positions to make sure that this did not have an effect on the readings of the guitar and motors tuning. Upon moving the guitar to different positions, such as being held normally instead of flat on the table, the tuner continued to work as expected.
d. Durability Tests
  i. To test durability, we attached the tuner to the end of the guitar and moved it as a normal guitarist might and made sure that the tuner did not move too much. The tuner would stay on with our current clamp design, however with too much movement, the tuner may fall off. This is expected though, as the design is supposed to be removable and therefore too much movement could potentially make it fall off. However, with normal, non rigorous movements, the tuner is very stable.

Status

The completed hardware elements of the project include a 3D printed case enclosing all components. Measurements for component lengths and the guitar were taken using a caliper for construction of the case in SolidWorks. This contains the six motors that are each attached to a tuning peg and a small hub that holds a rechargeable power bank to power the device and the LCD and push button user interface. The interface is attached to the outside of the case and painted to match. The circuitry itself has been condensed onto a perfboard to fit neatly between the motors. Consisting of the charge amplifier and schmitt trigger circuits, the output is sent to a secondary perfboard that holds the Adafruit RP2040 microcontroller. All wired connections are also hidden within the case. As for software, the accuracy of the frequency measurements has been improved enough to allow for correct tuning of the low E, D, and high E strings consistently.

Currently in progress is the design of a clamp to secure the device to the guitar. Also, the A, G, and B strings do not have a long enough signal received from each strum to get correct frequency measurements and instead need multiple strums to reach ten samples. Therefore, the charge amplifier and piezo sensor will be slightly modified to allow for more output to appear from the schmitt trigger. Once this is finished, the last planned element will be to further improve the measurements on the A, G, and B strings based on these changes. With a longer signal, more samples can be taken from a single strum of the guitar and will allow for less strums required to tune and a higher quality frequency being measured for all notes.


Figure 7: Project Timeline (Beta Build - Production Release)

Conclusion

In conclusion, the automatic guitar tuner project aims to develop an innovative solution that can make the process of tuning a guitar easier. With features such as an LCD interface with buttons and accurate frequency measurements, the tuner will provide reliable and consistent tuning for both beginners and experienced guitarists. Ultimately, the project seeks to enhance the quality and enjoyment of the guitar playing experience.

As for the future of this project, based on its current state at this time, additional testing can be made to optimize the frequency measurements. Our planned approach is to test different sensors to obtain a larger set of readings. Since all features have been implemented, the sensor can be replaced without it entirely altering the current state of this project. Overall, this project can currently tune a guitar reliably.

References

1. Colin, “Guitar tuners 101: The Ultimate Buyer's Guide,” E-Home Recording Studio, 02-Mar-2023. [Online]. Available: https://ehomerecordingstudio.com/best-guitar-tuners/. [Accessed: 24-Mar-2023].
2. E. Moffatt, “Nashville-based Gibson says self-tuning guitars are here to stay,” 90.3 WPLN News, 29-Jun-2015. [Online]. Available: https://wpln.org/post/nashville-based-gibson-says-self-tuning-guitars-are-here-to-stay/. [Accessed: 24-Mar-2023].
3. Evstark and Evstark, “Modeling and experimental tools with prof. magnes,” Modeling and Experimental Tools with Prof Magnes, 12-May-2019. [Online]. Available: https://pages.vassar.edu/magnes/2019/05/12/studying-and-modeling-guitar-harmonics-using-fourier-analysis/. [Accessed: 24-Mar-2023].
4. J. Karki, “Signal conditioning piezoelectric sensors - Texas Instruments,” TI, Sep-2000. [Online]. Available: https://www.ti.com/lit/an/sloa033a/sloa033a.pdf. [Accessed: 25-Mar-2023].
5. M. Gerić, G. Gajski, V. Oreščanin, A.-M. Domijan, R. Kollar, and V. Garaj-Vrhovac, “Environmental risk assessment of wastewaters from printed circuit board production: A multibiomarker approach using human cells Author links open overlay panel,” ScienceDirect, Feb-2017. [Online]. Available: https://doi.org/10.1016/j.chemosphere.2016.10.101. [Accessed: 24-Mar-2023].
6. “Roadie Tuner Automatic guitar tuner,” Agazoo, 10-Jun-2015. [Online]. Available: https://agazoo.com/offers/unique-gadgets/roadie-tuner-automatic-guitar-tuner/. [Accessed: 24-Mar-2023].
7. “Piezo tuners - the clip on Tuner,” SWAMP Industries, 26-Oct-2022. [Online]. Available: https://www.swamp.net.au/articles/piezo-tuners.html. [Accessed: 24-Mar-2023].

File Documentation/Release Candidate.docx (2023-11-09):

Q-Tune: Release Candidate

Yenessa Avalos-Maldonado, Timothy Chiles, William Trigg, Giovanni Cornejo, and Dakota Cappel

Github Link: https://github.com/avalosy8/qtune


Figure 1: Top down view of the completed Release Candidate (left). Side view of the device clamped onto the guitar, with the motor tuning attachment properly fitting onto the guitar’s tuning pegs (right).

External Interface

Our automatic guitar tuner’s external interface consists of a piezo vibration sensor, which connects as an input to the op-amp comparator circuit, and a servo motor that is driven by an output pin from the Adafruit RP 2040. The output of the comparator circuit is the input to the RX pin of the RP 2040, which is polled to start the frequency calculations. The external interface connects to the persistent state by the use of state variables and constants in memory, which are used to store the data obtained from the vibration sensor and comparator circuit. Additionally, all the hardware components have been condensed to fit within a 3D case as shown in Figure 1. The circuitry components have been moved and soldered onto two perfboards, one containing the Adafruit board and another containing the charge amplifier, filters, and comparator circuit. The entire device is attached to the guitar’s head using two clamps.

Persistent State

The guitar tuner stores its data via state variables and constants in memory. The constants are stored in onboard flash memory and are necessary for our internal tuning systems to run properly. The state variables are stored in RAM on the Adafruit board and are updated in response to input from the frequency-detecting components of our external interface. The persistent state connects to the external interface of our build through pins on the RP2040 microcontroller. The RX pin from the external interface is polled to start the frequency calculations. The persistent state stores this information to determine if the motors from our external interface need to turn the tuning pegs on the guitar. The persistent state connects to the interface system by also utilizing stored variables in order to process the necessary data to allow each component of our internal system to properly process data.

Internal Systems

Our three main internal systems are our frequency-detection system to determine the tuning of the guitar, our motor-turning system to alter the tuning of the guitar, and our UI system to allow users to interface with our guitar tuner. More advanced versions of the data processing involved in our three systems have been implemented. At present, the frequency-detection system can calculate the frequency of a guitar string via the external piezo sensor circuitry to some degree of accuracy. The motor-turning system can turn the motors in response to the frequency calculated with some degree of precision. The UI system allows users to select the string they want to tune and reports the tuner’s progress as a percentage. The internal system connects to the persistent state by the use of state variables and constants in memory to process the gathered data from each component.

Communication

The user will be interfacing with the LCD screen and two push buttons as a means of interacting with the tuner. The push buttons will be accessible to the user near the LCD screen, on the left and right side. These buttons accurately detect a selection made by the user and displays the correct string that was selected and its targeted frequency. Thus, the user will be able to intuitively select the desired string to tune. After making a selection,the user will just have to view the LCD screen to be notified about whether the guitar string needs to be strummed again based on tuning percentage. When the measured frequency isn’t close to the target frequency within an acceptable range then the motors move the tuning peg as expected and the user is prompted to strum the guitar string again.

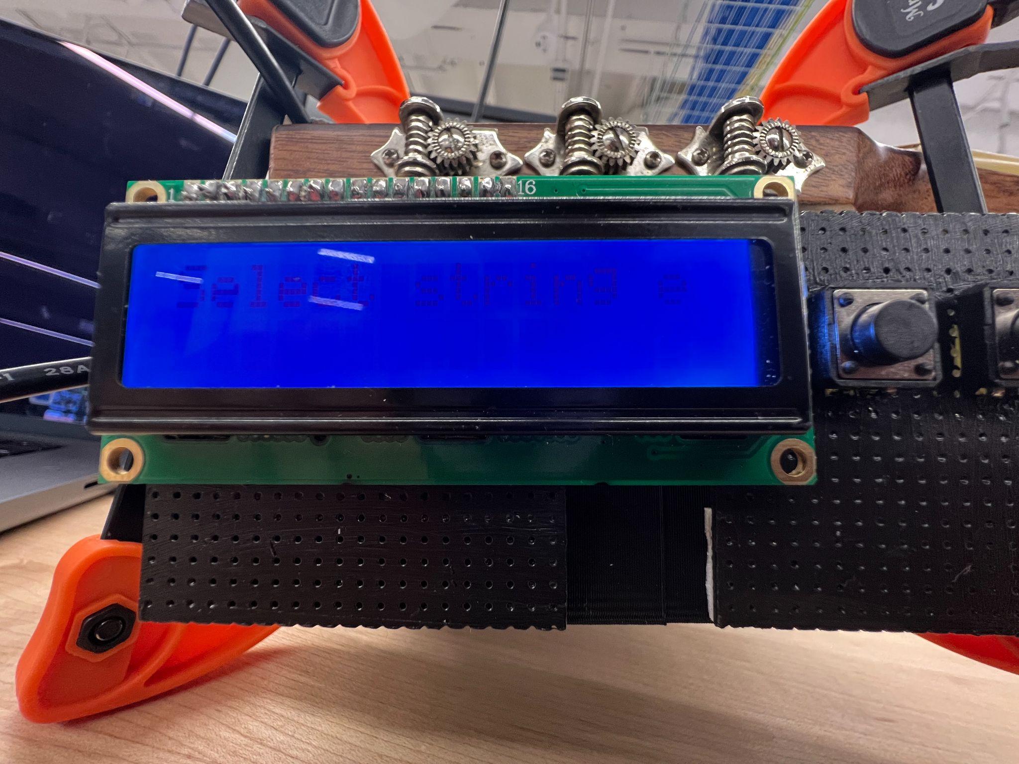
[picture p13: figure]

Figure 2: User is first prompted to select a string.

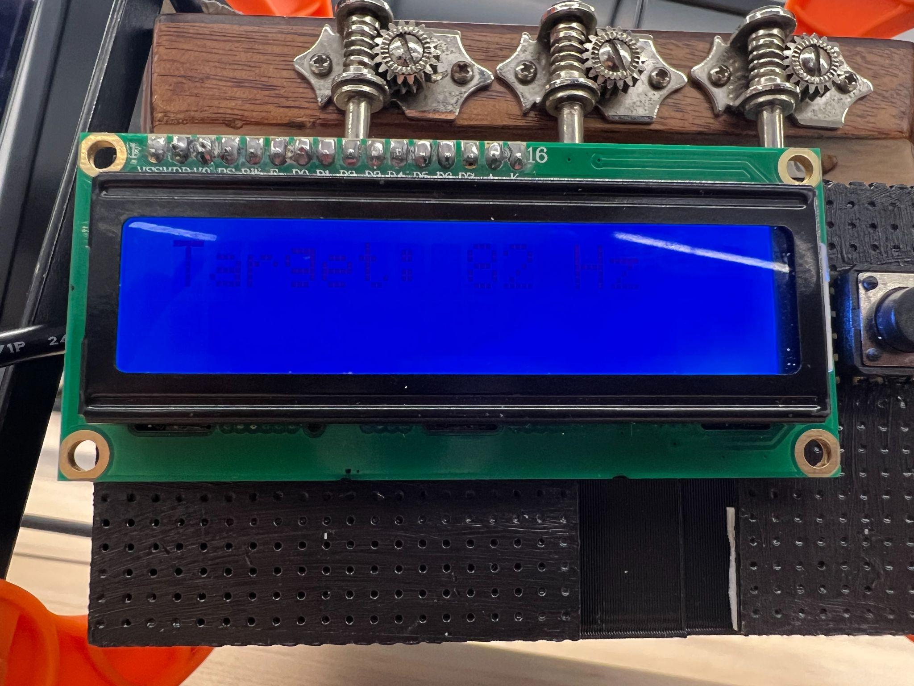
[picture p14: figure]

Figure 3: After the string is selected, its target frequency is displayed.

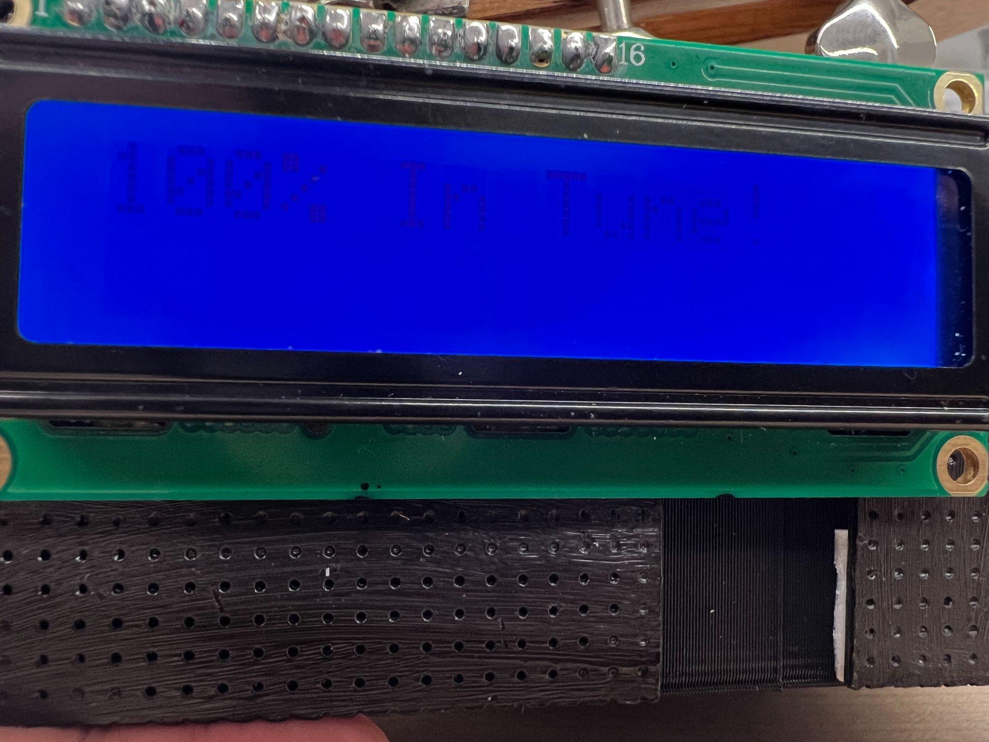
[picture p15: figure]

Figure 4: Percentage of how tuned the selected string is. This is displayed after the frequency is measured.

Integrity & Resilience

When running the program normally, the device is able to run through menu options, display the desired frequency, display the measured frequency and tuning progress percentage, and turn the motor without any crashing or system failures. There are multiple filters in-place, both in hardware and software, to ensure that the system does not pick up unwanted frequencies and produce undesired results such as improper tuning. When the second harmonic of the strings appears more strongly at the input than its fundamental frequency, our code has the infrastructure in place to account for the doubled frequencies. All random instances of crashes have been debugged and dealt with as well, creating a smooth and consistent user experience. Furthermore, the responsiveness of the buttons is immediate, without bouncing or false input detections, and accurately selects the string to be tuned. Once the motors move, the LCD screen immediately notifies the user whether the target frequency was reached.

The measured frequencies remain consistent as we have the signal fed through a charge amplifier and a Schmitt Trigger. The charge amplifier makes the resultant sine wave reflect the vibration of the guitar more accurately because the piezo produces a proportional charge to mechanical stress, not a proportional voltage. The charge amplifier also nulls the effects the piezo sensor and its cable’s internal capacitance could potentially have on our signal. The charge amplifier eliminates noise by only allowing frequencies within the guitar’s expected operating range (~60-360Hz) to continue through the circuitry. The Schmitt Trigger can produce a clean and accurate square wave representation from potentially noisy sinusoidal signals via its two threshold voltages.

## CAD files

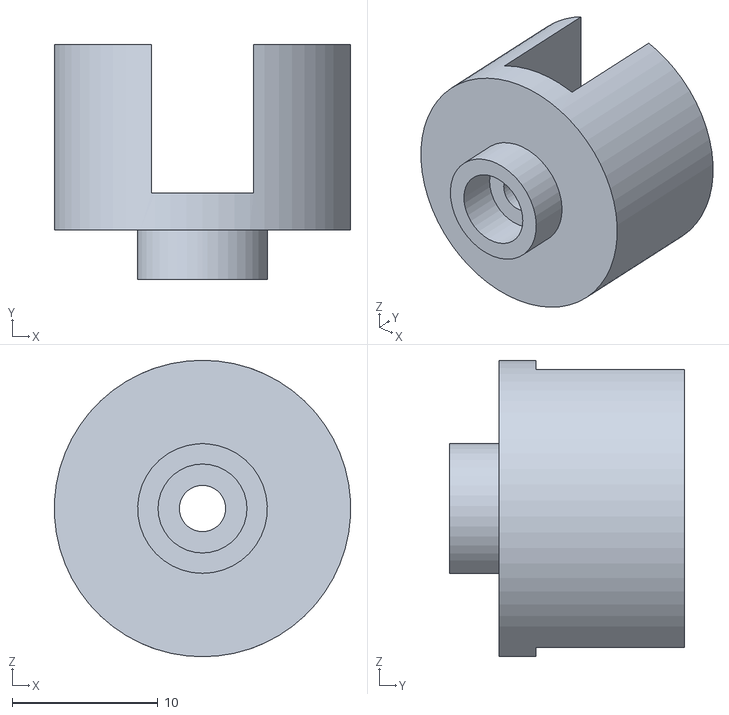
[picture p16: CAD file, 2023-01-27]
SolidWorks Schematics/ChilesTuningAttach3.STL
20.3 x 16.1 x 20.3

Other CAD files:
SolidWorks Schematics/ChilesTuningAttach4.STL
SolidWorks Schematics/ChilesTuningAttach2.STL
SolidWorks Schematics/tuningEnclosure.STL

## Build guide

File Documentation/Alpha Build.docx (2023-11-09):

Q-Tune: Alpha Build

Yenessa Avalos-Maldonado, Timothy Chiles, and William Trigg

Github Link: https://github.com/avalosy8/qtune

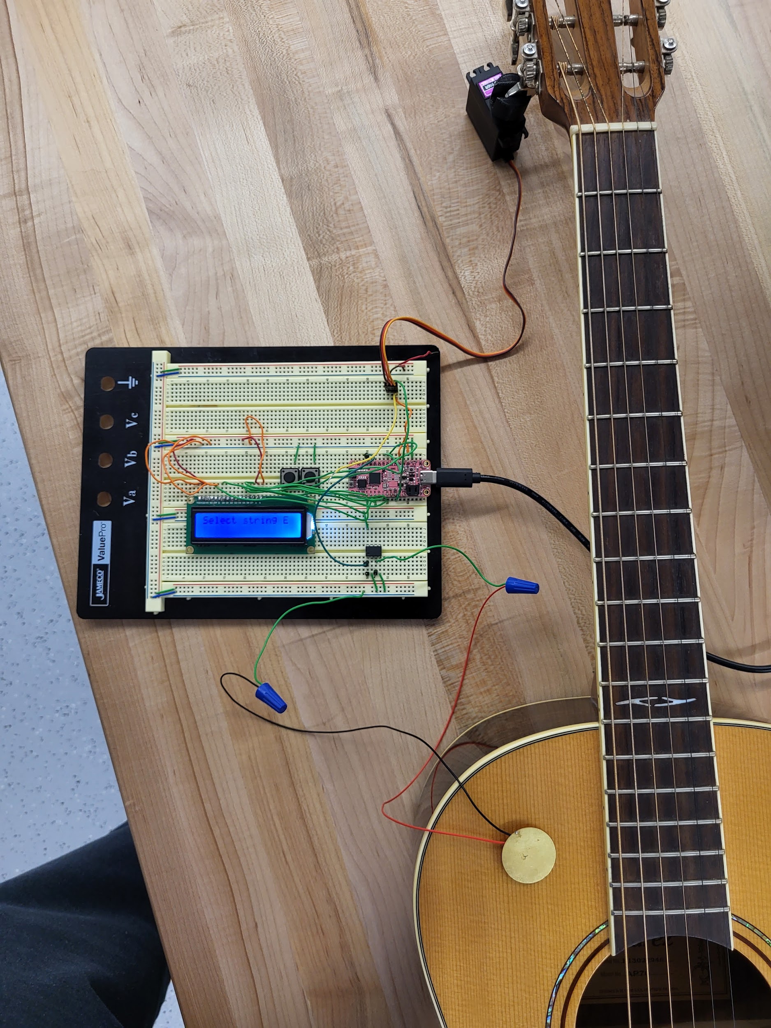
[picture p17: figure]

Image 1: Completed Alpha Build

Usability

Interface

The LCD screen accurately displays the processed readings from the vibration sensor. There are two debounced push buttons that allow the user to select a string to tune. As the program is running, the frequency readings are displayed and notifies the user when the frequency is either too high or too low, which indicates that the tuning pegs will be adjusted and that the user needs to strum the guitar strings again to re-measure the frequency values.

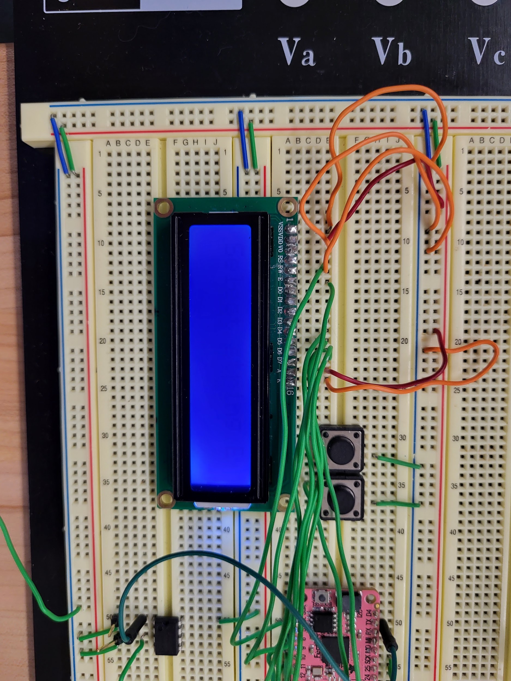
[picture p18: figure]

Image 2: UI for the automatic guitar tuner including the LCD screen and push buttons

Navigation

When the measured frequency isn’t close to the target frequency, within an acceptable range, then the motors move the tuning peg as expected. Additionally, the push buttons accurately detect a selection made by the user and display the correct string that was selected and the targeted frequency. The user is then notified via the LCD screen whenever they need to strum the strings again to retune the guitar string.

Perception

The push buttons will be accessible to the user near the LCD screen, on the left and right side. The users will be able to intuitively select the string they wish to tune by pressing these buttons. After the motors move, the user will just have to view the LCD screen to be notified about whether the guitar string needs to be strummed again.

Responsiveness

The responsiveness of the buttons is immediate, without bouncing or false input detections, and accurately selects the string to be tuned. Once the motors move, the LCD screen immediately notifies the user whether the target frequency was reached. To reduce idle time length and conflicts between tasks, we use asynchronous functions for moving the motors and measuring/displaying the current frequency values on the LCD screen.

Build Quality

Robustness

When running the program normally, the device is able to run through menu options, display the desired frequency, display current frequency, and turn the motor without any crashing or system failures.

Consistency

At the current state, we are in the process of switching to a larger motor in order to ensure that we have the proper torque needed to turn the pegs of the guitar. This has caused some unexpected inconsistency when running the entire program, which can be expected when implementing a new component. Our design will function properly up until attempting to turn the motor, where the program may act unexpectedly and not turn the motor. Our design with the old motor worked consistently and we expect the same once we figure out the specific issues with the changes of our motor and its integration into our system. We plan to try different ways to power the motor which we suspect is the main cause of this issue. We also will evaluate the code and see if there are any necessary changes that need to occur there.

Aesthetic Rigor

The LCD screen properly and consistently produces the correct tuning options and frequencies corresponding to that tuning. The menu is simplistic and intuitive so that any user can pick up the device and use it. Current hardware will be condensed and hidden into a single 3D-printed device to make for a more aesthetic design.

Vertical Features

External Interface

Our automatic guitar tuner’s external interface consists of a piezo vibration sensor, which connects as an input to the op-amp comparator circuit, and a servo motor that is driven by an output pin from the RP 2040. The output of the comparator circuit is the input to the RX pin of the RP 2040, which is used to trigger an interrupt and start the frequency calculations. The external interface connects to the persistent state by the use of state variables and constants in memory, which are used to store the data obtained from the vibration sensor and comparator circuit.

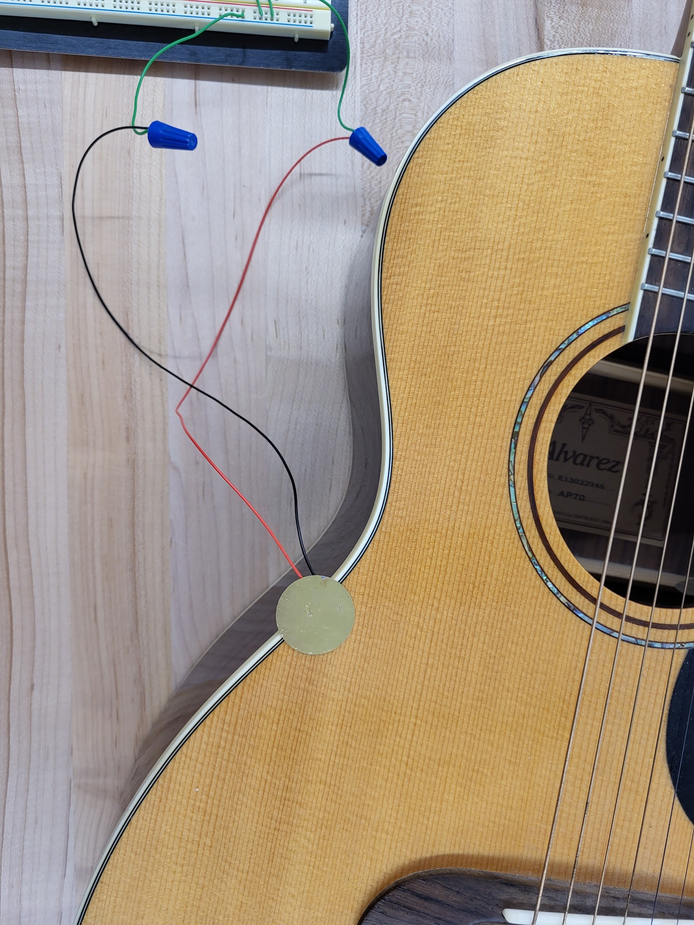
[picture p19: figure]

Image 3: Piezo sensor that detects frequency of guitar strings

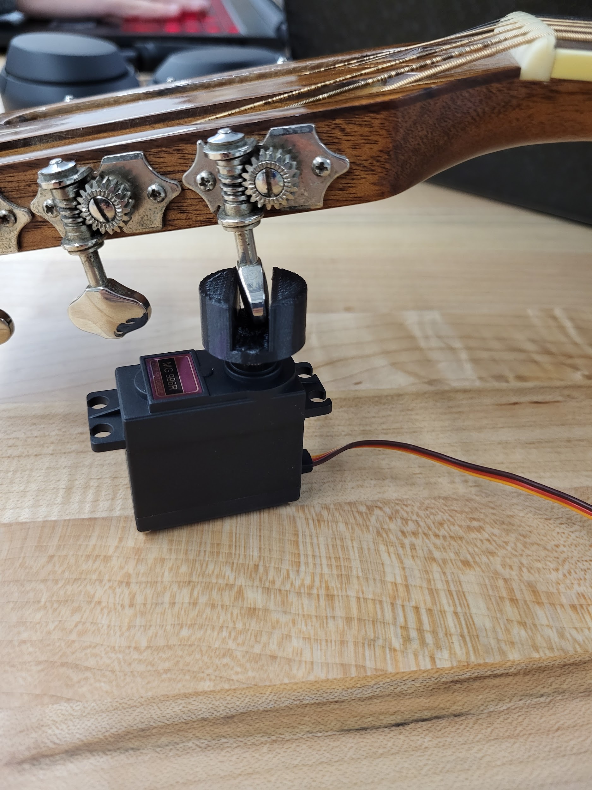
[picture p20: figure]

Image 4: Servo motor with 3D-printed tuning attachment used to tune the guitar

Persistent State

The guitar tuner stores its data via state variables and constants in memory. The constants are stored in onboard flash memory and are necessary for our internal tuning systems to run properly. The state variables are stored in RAM on the Adafruit board and are updated in response to input from the frequency-detecting components of our external interface. The persistent state connects to the external interface of our build through pins on the RP2040 microcontroller. The RX pin from the external interface is configured as an interrupt pin, which starts the frequency calculations. The persistent state stores this information to determine if the motors from our external interface need to turn the tuning pegs on the guitar. The persistent state connects to the interface system by also utilizing stored variables in order to process the necessary data to allow each component of our internal system to properly process data.

Internal Systems

Our three main internal systems are our frequency-detection system to determine the tuning of the guitar, our motor-turning system to alter the tuning of the guitar, and our UI system to allow users to interface with our guitar tuner. Preliminary versions of the data processing involved in our three systems have been implemented. At present, the frequency-detection system can calculate the frequency of a guitar string via the external piezo sensor circuitry to some degree of accuracy. The motor-turning system can turn the motors in response to the frequency calculated with some degree of precision. The UI system allows users to select the string they want to tune and reports whether the string is tuned too high, too low, or in tune. The internal system connects to the persistent state by the use of state variables and constants in memory to process the gathered data from each component.

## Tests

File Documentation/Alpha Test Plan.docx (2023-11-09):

Q-Tune: Alpha Test Plan

Yenessa Avalos-Maldonado, Timothy Chiles, and William Trigg

Expected Behavior

a. The motors used should be able to be driven by a PWM signal from the Adafruit RP 2040 while being powered by the Adafruit RP 2040 or an external battery.
b. All components of the tuner (Adafruit RP 2040, LCD display, 6 servo motors, etc.) should be able to be powered by an external battery simultaneously.
c. 3D-printed tuning motor attachment should attach to the motor with ease and be secure as to properly tune the guitar peg.
d. The tuner should be able to tune all guitar strings to within 2 Hz of the actual in-tune frequency 80% of the time.

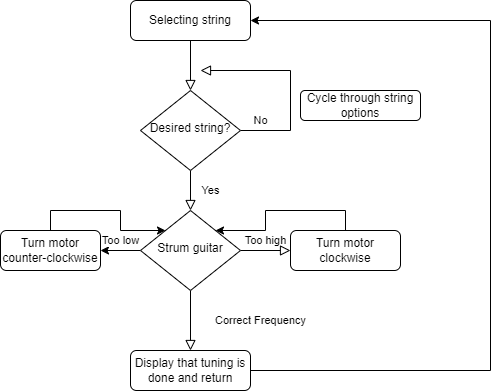
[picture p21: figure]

Figure 1: The overall flow of the expected behavior of the alpha build.

For each specified expected behavior, a test procedure for it is further outlined below

Test Procedures

a. For each servo motor on hand:
1. Attach 3D-printed tuning attachment to servo motor and to tuning peg of a guitar
2. Plug test power source into relevant wires of servo motor and Adafruit PWM pin into data line of motor
3. Run test code that tests motor turning clockwise, counter-clockwise, and stopping
4. Record whether motor turns and if it has enough torque to turn tuning peg of guitar
5. Repeat steps 1-4 with all potential power sources (3.3V, 5V USB, 3.7V Lipo battery, 4.5V and 6V (AA batteries)). Record suitable voltage/motor combinations for future use.
b. Determine the total power needed for our system and compare it to possible power from the batteries. Test different power sources by gradually adding components and examine how the system responds.
  1. Separate each component of our internal system into small measurable parts
  2. Measure the voltage and current of each component
  3. Using one component, add another component to it and remeasure the overall voltage and current
  4. Observe and record how the system behaves
  5. Repeat 3 and 4 until all the components are connected
  6. Determine the overall power needed for our system and compare it against possible battery options
c. For each 3D printed tuning attachment:
1. Attach it to the servo motor by sliding it onto the motor shaft and screwing in. Record the fit of the attachment (snug, loose, does not fit)
2. Slide the relevant end of the attachment onto the tuning peg of the guitar. Record fit of attachment on tuning peg
3. Run test code that turns the motor. Record whether motor successfully turns tuning peg
4. Repeat steps 1-3 for all tuning attachments on hand. Make qualitative assessment of tuning attachments to select the best candidate for future use. Make changes to CAD files and reprint if necessary
d. For each guitar string:
1. Manually turn the string’s tuning peg until the oscilloscope reports the string is at the desired starting frequency
2. Select the relevant string on the LCD and strum the string when prompted
3. Measure the frequency of the string with an oscilloscope once the tuner is finished tuning
4. Record the end frequency of the string. Repeat steps 1-3 until starting frequencies of in-tune frequency +/- 15 Hz, +/- 10 Hz, and +/- 5 Hz have been tested
5. Compile results, make adjustments to hardware/software, and repeat testing procedure until desired accuracy has been reached

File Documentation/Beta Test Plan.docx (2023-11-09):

Q-Tune: Beta Test Plan

Yenessa Avalos-Maldonado, Timothy Chiles, William Trigg, Giovanni Cornejo, and Dakota Cappel

Github Link: https://github.com/avalosy8/qtune

Alpha Test Results

a. Powering/Turning servos
  i. After determining that we had enough available pins on the Adafruit board, we connected all six servo motors and used different power sources levels to find the proper voltage level we needed to power the motors. After testing, we concluded that 5V was enough to power the motors. We no longer use the default 3.3V on the Adafruit board in our circuitry and instead use the USB pin to obtain 5V.
b. Determining total power required
  i. After testing, we concluded that all components of our guitar tuner could be powered simultaneously via the 5V and 3.3V pins on the Adafruit board. The Adafruit board could successfully power its internal components, the LCD display, the piezo sensor’s circuitry, and at least 1 servo motor at a time via a USB power bank plugged into its USB-C port. We did not test turning more than 1 servo motor at a time as our project does not require this functionality. We determined that a USB power bank is a suitable power source for our final tuner design as it can make the whole tuner rechargeable and easily able to be turned on and off.
c. Testing 3D printed tuning attachment
  i. Once the tuning attachment design has been finalized and printed, we screwed the attachments onto each six servo motors and tested them against each tuning peg. We turned the motor in small increments and tested how much strength was needed to actually turn the tuning peg. After testing, we’ve concluded that the tuning attachment design was enough to properly turn the tuning pegs when the motors are signaled move. Further modification may be made for the tuning attachments, but the design is finalized for the most part.
d. Testing tuner for each string
  i. As we began testing the accuracy of our tuner as a whole, we determined that more circuitry was required to condition the signal from our piezo sensor (amplification, filtering, noise reduction, removal of DC offset). After implementing this new functionality, we encountered an issue where the second harmonic of each string was appearing more so than the fundamental frequency we were looking for in code. We added more checks in our code to account for this issue. When testing our tuner after these progressions, we achieved our first successful tuning of the low E string. Despite this breakthrough, more testing and tweaking of our tuning procedure needs to take place during the next stage of the project.

Expected Behavior

a. The tuner should be able to tune all guitar strings to within 1 Hz of the actual in-tune frequency 90% of the time.
b. The tuner should produce accurate results to within 2 Hz of the actual in-tune frequency while the guitar is placed in different environments (outdoors, indoors, with surrounding noise, etc.) and while the guitar is held in different positions 80% of the time.
c. The 3D-printed tuning device should attach to the motor with ease and be secure as to properly tune the guitar peg. Motion from tuning, and sudden motion from the guitar (within reason) should not dislocate or negatively affect the device


Figure 1: The overall flow of the expected behavior of the beta build.

For each specified expected behavior, a test procedure for it is further outlined below

Test Procedures

a. For each guitar string:
1. Manually turn the string’s tuning peg until the oscilloscope reports the string is at the desired starting frequency
2. Select the relevant string on the LCD and strum the string when prompted
3. Measure the frequency of the string with an oscilloscope once the tuner is finished tuning
4. Record the end frequency of the string. Repeat steps 1-3 until starting frequencies of in-tune frequency +/- 15 Hz, +/- 10 Hz, and +/- 5 Hz have been tested
5. Compile results, make adjustments to hardware/software, and repeat testing procedure until desired accuracy has been reached
b. For each environment/position:
1. Manually turn the string’s tuning peg until the oscilloscope reports the string is at the desired starting frequency
2. Hold the guitar in different positions and move into different environments
3. Select the relevant string on the LCD and strum the string when prompted
4. Measure the frequency of the string with an oscilloscope once the tuner is finished tuning
5. Record the end frequency of the string, the environment, and the position of the guitar. Repeat steps 1-3 until starting frequencies of in-tune frequency +/- 15 Hz, +/- 10 Hz, and +/- 5 Hz have been tested
6. Compile results, make adjustments to hardware/software, and repeat testing procedure until desired accuracy has been reached
c. Check that sudden motion does not dislocate or harm the 3D-printed device while tuning
1. Perform many tuning to observe the durability of the 3D-printed parts and ensure that there is minimum wear
2. Ensure that screws remain tight and unaffected by turns made with the tuner.
3. Manually turn each string’s tuning peg until all are out of tune
4. Tune all strings in one sitting to ensure that the motors do not affect each other

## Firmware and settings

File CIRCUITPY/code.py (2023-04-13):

import board
import countio
import time
import pulseio
import pwmio
import digitalio
from adafruit_motor import servo
import adafruit_character_lcd.character_lcd as characterlcd
import random

try:
  import ulab.numpy as np
except ImportError:
  import numpy as np

###################### FUNCTIONS ######################
def init(lcd, button1, button2, start_threshold, stop_threshold):
    """
    Initializes Tuning
    
    Gets the user input on what string to tune and sets up variables accordingly
    
    Parameters:
    lcd (character_lcd): The module for interfacing with monochromatic character LCDs
    button1 (DigitalInOut): The "change" button
    button2 (DigitalInOut): The "start" button"
    start_threshold (float): The frequencies considered for tuning (target +/- start_threshold)
    stop_threshold (float): The frequencies considered in tune (target +/- stop_threshold)
    
    Returns:
    str: The current selected note
    int: The servo to be used
    list: Target limits
    list: Passband limits
    """
    
    # INITIALIZE NOTE VARIABLES #
    string_notes = {'e': 82.41, 'A': 110.00, 'D': 146.83, 'G': 196.00, 'B': 246.94, 'E': 329.63 }
    notes = {0: 'e', 1: 'A', 2: 'D', 3: 'G', 4: 'B', 5: 'E'}
    curr_note = 'e'
    notes_to_servo = {'e': 0, 'A': 1, 'D': 2, 'G': 3, 'B': 4, 'E': 5} # for moving servos
    curr_servo = 0
    
    # RESET #
    time.sleep(0.5)
    lcd.clear()
    selected = False
    idx = 0
    note = notes[idx]

    # WAIT UNTIL USER SELECTS A STRING #
    while not selected:
        # Check if Select String button pressed
        if not button2.value:
            selected = True
        # Check if Change String button pressed
        if not button1.value:
            # Increment Index
            idx = idx + 1 if idx < 5 else 0

            time.sleep(0.5)  # Debounce Button
            note = notes[idx] # Update String Note
        lcd.message = "Select String\nCurrent: \'" + note + "\'"

    # INITIALIZE VARIABLES #
    # Update the Target Frequency and Set Current Servo
    curr_note = note
    target_freq = string_notes[note]
    curr_servo = notes_to_servo[note]

    # Calculate Limits of Target Frequency and Pass Band Filter
    target_freq_low = target_freq - stop_threshold
    target_freq_high = target_freq + stop_threshold
    double_target_freq_low = target_freq*2 - stop_threshold
    double_target_freq_high = target_freq*2 + stop_threshold
    target_limits = [target_freq_low, target_freq_high, double_target_freq_low, double_target_freq_high]
    pass_band_low = target_freq - start_threshold
    pass_band_high = target_freq + start_threshold
    double_pass_band_low = target_freq*2 - start_threshold
    double_pass_band_high = target_freq*2 + start_threshold
    pass_band_limits = [pass_band_low, pass_band_high, double_pass_band_low, double_pass_band_high]
    
    return curr_note, curr_servo, target_limits, pass_band_limits


def tune(freq, turned_servo, throttle, pass_band_low, pass_band_high, target_freq_low, target_freq_high):
    """
    Tune Current String with Motor
    
    Uses the passed in frequency to determine whether the string is in tune. If not,
    the motor attached to the string is turned clockwise or counterclockwise
    
    Parameters:
    freq (float): The frequency to compare with the target frequency
    turned_servo (PWMOut): The servo to turn if string is out of tune
    pass_band_low (float): The lower limit of the passband
    pass_band_high (float): The upper limit of the passband
    target_freq_low (float): The lower limit of the target frequency
    target_freq_high (float): The upper limit of the target frequency
    
    Returns:
    bool: If the string is in tune or not
    str: The completion bar of how much the string is in tune
    """
    
    # Check if Frequency is in Target Frequency Limits
    percent_tuned = -1
    if (freq > target_freq_low) and (freq < target_freq_high):
        return True, None

    # If Frequency is Greater than Target Frequency
    if freq > target_freq_high:
        percent_tuned = map_to(freq, pass_band_high, target_freq_high, 0, 100)

    # If Frequency is Less than Target Frequency
    elif freq < target_freq_low:
        percent_tuned = map_to(freq, pass_band_low, target_freq_low, 0, 100)
        throttle = throttle*-1
    interval = map_to(percent_tuned, 100, 0, 0.05, 1.0)
    
    # Tune Guitar by Moving Servos
    turned_servo.throttle = throttle
    time.sleep(interval)
    turned_servo.throttle = 0

    # Create Bar for Progress to In Tune
    tune_bar = '['
    prog = int(map_to(percent_tuned, 0, 100, 0, 13))
    for x in range(prog):
        tune_bar += '*'
    while len(tune_bar) != 15:
        tune_bar += ' '
    tune_bar += ']'    
    return False, tune_bar


def read_freq(rx, pulse_length, button2):
    """
    Calculate Frequency of Input Waveform
    
    Fills the PulseIn object with times for the high and low segments of the waveform
    until the provided pulse length is reached. The average time is received and then
    converted to a frequency by taking the reciprocal
        
    Parameters:
    rx (PulseIn): Object that measures the time of each period
    pulse_length (int): How many measurements to be taken
    button2: (DigitalInOut): The "reset" button
    
    Returns:
    float: The measured frequency
    """
    
    # Reset pulseio pin
    rx.clear()
    rx.resume()
    
    while True:
        # Check if Restart Button was Pressed
        if not button2.value:
            return -1

        # Wait for Pulses to be Read
        if len(rx) == pulse_length:
            rx.pause()
            sum = 0
            val = 0

            # Sum all Pulse Times
            for i in range(0, pulse_length, 2):
                # Exclude Pulse Times Greater than Expected
                if rx[i] < 10000 and rx[i+1] < 10000:
                    sum += rx[i] + rx[i+1]
                else:
                    val = val + 2

            # Convert to Frequency with Average Pulse Time
            freq = 1 / ((sum / ((pulse_length - val)/2)) / 1000000)
            return freq

def map_to(x, in_min, in_max, out_min, out_max):
    """
    Helper function that maps a value from one range to another
    
    Parameters:
    x (float): The value mapped in the input range
    in_min (float): The minimum value of the input range
    in_max (float): The maximum value of the input range
    out_min (float): The minimum value of the output range
    out_max (float): The maximum value of the output range
    
    Returns:
    float: The value mapped in the output range
    """
    return (x - in_min) * (out_max - out_min) / (in_max - in_min) + out_min


# Main
def main():
    ####################### SERVO CONFIGURATION ########################
    servo1 = servo.ContinuousServo(pwmio.PWMOut(board.D13, frequency=50))
    servo2 = servo.ContinuousServo(pwmio.PWMOut(board.SCL, frequency=50))
    servo3 = servo.ContinuousServo(pwmio.PWMOut(board.SDA, frequency=50))
    servo4 = servo.ContinuousServo(pwmio.PWMOut(board.D25, frequency=50))
    servo5 = servo.ContinuousServo(pwmio.PWMOut(board.D24, frequency=50))
    servo6 = servo.ContinuousServo(pwmio.PWMOut(board.A2, frequency=50))
    servos = [servo1, servo2, servo3, servo4, servo5, servo6]

    ######################## LCD CONFIGURATION #########################
    lcd_rs = digitalio.DigitalInOut(board.D5)
    lcd_en = digitalio.DigitalInOut(board.D6)
    lcd_d7 = digitalio.DigitalInOut(board.D12)
    lcd_d6 = digitalio.DigitalInOut(board.D11)
    lcd_d5 = digitalio.DigitalInOut(board.D10)
    lcd_d4 = digitalio.DigitalInOut(board.D9)
    lcd_backlight = digitalio.DigitalInOut(board.D4)
    lcd_columns = 16
    lcd_rows = 2
    lcd = characterlcd.Character_LCD_Mono( # Initialize the lcd class
        lcd_rs, lcd_en, lcd_d4, lcd_d5, lcd_d6,
        lcd_d7, lcd_columns, lcd_rows, lcd_backlight)

    ###################### BUTTON CONFIGURATION ########################
    button1 = digitalio.DigitalInOut(board.A1) # Change String
    button1.direction = digitalio.Direction.INPUT
    button1.pull = digitalio.Pull.UP

    button2 = digitalio.DigitalInOut(board.A0) # Select String
    button2.direction = digitalio.Direction.INPUT
    button2.pull = digitalio.Pull.UP

    ############## FOR TESTING PURPOSES (DETUNE GUITAR) ################
    lcd.clear()
    lcd.message = " Detune Guitar? \n   [Yes] [No]"
    time.sleep(0.5)
    while True:
        if not button1.value:
            throttle = -0.5
            for i in range(0, 6):
                interval = map_to(random.random(), 0, 1.0, 0.3, 0.7)
                detune_servo = servos[i]
                detune_servo.throttle = throttle
                time.sleep(interval)
                detune_servo.throttle = 0
                throttle = throttle*-1
            break
        elif not button2.value:
            break
    ####################################################################
    
    ######################### START OF PROGRAM #########################
    # Welcome User to QTune
    lcd.clear()
    lcd.message = "Welcome to QTune"
    time.sleep(2)

    while True:
        # User Selects a String
        start_threshold = 15 # Range of Frequencies Considered
        stop_threshold = 0.5 # Range of Frequencies Considered In Tune
        curr_note, curr_servo, target_limits, pass_band_limits = init(lcd, button1, button2, start_threshold, stop_threshold)
        time.sleep(0.5)
        
        # Target Frequency (Lower/Upper Limit of "In Tune" Frequencies for a Note)
        target_freq_low = target_limits[0]
        target_freq_high = target_limits[1]
        double_target_freq_low = target_limits[2]
        double_target_freq_high = target_limits[3]
        # Pass Band Filter (Lower/Upper Limit of Frequencies for Filter)
        pass_band_low = pass_band_limits[0]
        pass_band_high = pass_band_limits[1]
        double_pass_band_low = pass_band_limits[2]
        double_pass_band_high = pass_band_limits[3]

        # Initialize Tuning Process and Inform User to Strum
        sampling_sizes = {'e': 5, 'A': 5, 'D': 5, 'G': 5, 'B': 5, 'E': 5}
        pulse_lengths = {'e': 100, 'A': 100, 'D': 140, 'G': 150, 'B': 300, 'E': 300}
        sampling_size = sampling_sizes[curr_note]
        pulse_length = pulse_lengths[curr_note]
        
        # Initialize PulseIn object
        rx = pulseio.PulseIn(board.RX, pulse_length, False)
        rx.pause()
        
        in_tune = False
        restart = False
        tune_bar = "[              ]"
        while not in_tune:
            
            lcd.clear()
            lcd.message = "Strum the \'" + curr_note + "\'\n" + tune_bar
            # Begin Reading Frequencies
            frequencies = []
            double_frequencies = []

            while len(frequencies) < sampling_size and len(double_frequencies) < sampling_size:
                # Calculate Frequency
                curr_freq = read_freq(rx, pulse_length, button2)
                
                # Check if Restart Button was Pressed
                if curr_freq == -1:
                    restart = True
                    break

                # If current frequency is in acceptable range
                if curr_freq >= pass_band_low and curr_freq <= pass_band_high:
                    frequencies.append(curr_freq)
                    print("\nSamples: " + str(len(frequencies)) + "/" + str(sampling_size) + " and Doubled " + str(len(double_frequencies)) + "/" + str(sampling_size))

                # Check doubled frequency range
                elif curr_freq >= double_pass_band_low and curr_freq <= double_pass_band_high:
                    print("\nSamples: " + str(len(frequencies)) + "/" + str(sampling_size) + " and Doubled " + str(len(double_frequencies)) + "/" + str(sampling_size))
                    double_frequencies.append(curr_freq/2)

            if restart == True:
                break

            # Determine List to Use
            curr_freqs = []
            if len(double_frequencies) == sampling_size:
                curr_freqs = double_frequencies
            else:
                curr_freqs = frequencies
            curr_freqs.sort()
            used_freqs = curr_freqs

            # If Range is Too Big Remove Outliers with IQR
            difference = curr_freqs[-1] - curr_freqs[0]
            print(curr_freqs)
            print(difference)
            if difference > stop_threshold:
                curr_freqs = np.array(curr_freqs) # Convert to Numpy array
                Q1 = np.median(curr_freqs[:int(sampling_size/2)])
                Q3 = np.median(curr_freqs[int(sampling_size/2):])
                curr_freqs = [x for x in curr_freqs if (x >= Q1 and x <= Q3)]
                print(curr_freqs)
                
                # If Range too Big, remove End Caps
                difference = curr_freqs[-1] - curr_freqs[0]
                print(difference)
                if (difference > stop_threshold*3):
                    if len(curr_freqs) > 2:
                        del curr_freqs[-1]
                        del curr_freqs[0]
                    # If too Innaccurate to Average
                    else:
                        lcd.clear()
                        lcd.message = "Invalid read\ntry again!"
                        time.sleep(1.5)
                        continue

                used_freqs = curr_freqs

            # Calculate Average Frequency
            print(used_freqs)
            average_freq = sum(used_freqs) / len(used_freqs)

            # Turn Motor to Tune or Finish Tuning
            turned_servo = servos[curr_servo]
            throttle = 0.5
            if curr_servo > 3:
                throttle = 0.3
            in_tune, tune_bar = tune(average_freq, turned_servo, throttle, pass_band_low, pass_band_high, target_freq_low, target_freq_high)
            if in_tune:
                lcd.clear() # Inform User
                lcd.message = "100% in tune\n[**************]"
                time.sleep(2)
            else:
                lcd.clear()
                lcd.message = "Strum Again!\n" + tune_bar

        rx.deinit()

if __name__ == "__main__":
    main()

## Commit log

2022-11-02 Create README.md
    servo motor code and README.md added
2022-11-17 turning two motors
2023-01-26 updating to prototype version
2023-02-07 all 6 motors are configured to a pin and can move one at a time, edited functions to move one servo at a time (to test later)
2023-02-16 code that moves one servo at a time (need to debug)
2023-02-16 fixed code so that motors turn one at a time
    [code.py]
2023-03-07 added dependencies and circuitpy folder
2023-03-08 Replaced monotonic_ms with pulseio
    Produces much more reliable and precise results for calculating frequency from comparator
    [code.py]
2023-03-20 adding directory for solidworks files
    [ChilesTuningAttach2.STL, ChilesTuningAttach3.STL, ChilesTuningAttach4.STL]
2023-03-20 Delete ChilesTuningAttach2.STL
    moved to own directory
    [ChilesTuningAttach2.STL]
2023-03-20 Delete ChilesTuningAttach3.STL
    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
    [ChilesTuningAttach3.STL]
2023-03-20 Delete ChilesTuningAttach4.STL
    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
    [ChilesTuningAttach4.STL]
2023-03-24 Adding battery attachment file
    [Battery Attachment.SLDPRT]
2023-03-30 Fine-tuned motor movement
    Also added correct note frequencies instead of integers
    [code.py]
2023-04-04 Fixed lcd pins
    Also increased accuracy to within +/- 0.5 Hz
    [code.py]
2023-04-12 Adding finalized battery attachment
    [Battery Attachment.SLDPRT]
2023-04-13 Finalized the code
    Changed throttle for different strings
    Fine tuned time interval for motor turn
    Cleaned up IQR and average for precision
